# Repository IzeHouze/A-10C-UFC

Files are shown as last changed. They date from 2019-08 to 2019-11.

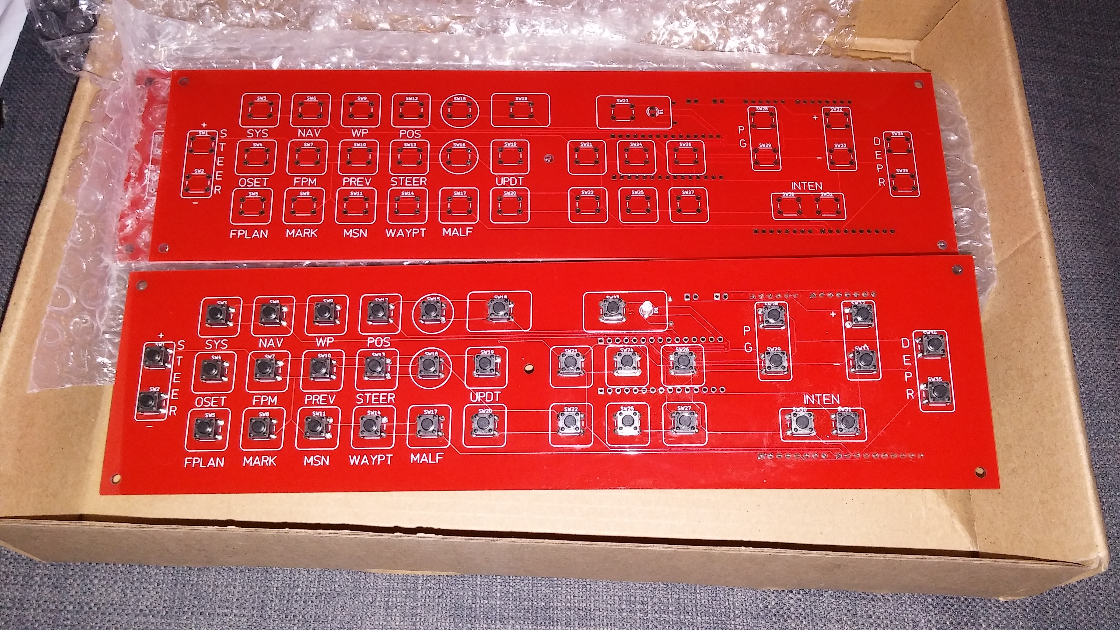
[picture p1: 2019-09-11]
CompletedFront.jpg

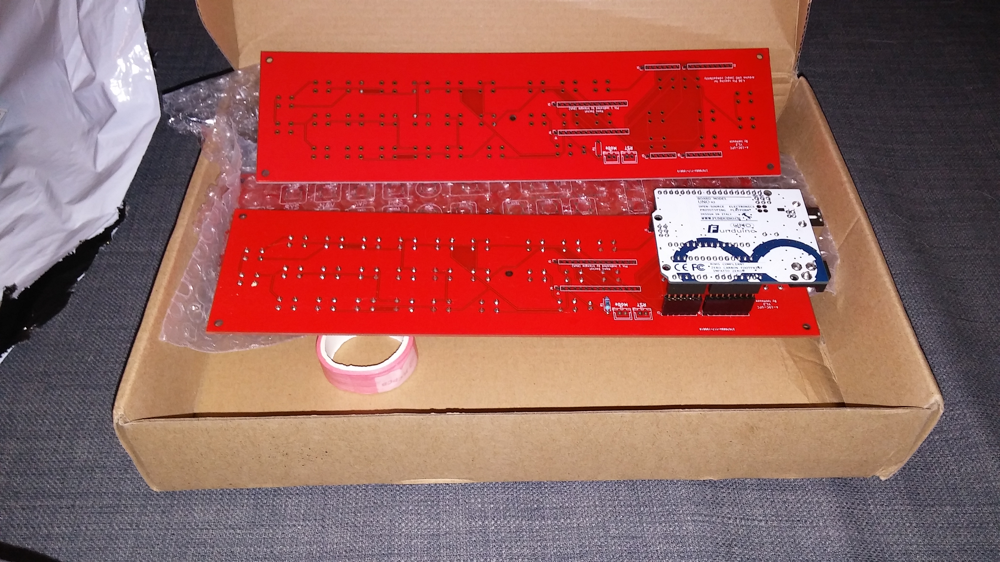
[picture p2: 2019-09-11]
CompletedBack.jpg

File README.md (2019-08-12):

# A-10C-UFC
DCS A-10C UFC

This project is basically a home grown attempt to create a functional UFC for the A-10C module of the flight sim DCS World.
It is based on a simple 6x6 keyboard matrix interfaced to the PC via an Arduino Microcontroller.  There are the wiring scematics, a PCB layout and Blender files for an enclosure which should be 3D printable.

The PCB has sockets for plug in capability of either the Uno or Nano variety of Arduino Controller.

The code was originally created to work specifically for the A-10C module, however, since the F/A-18 simulation also has a UFC, there is an optional connection for a switch which can be used to change modes between the A-10 and the F-18.  There is also a connector for an external reset switch, which would be best used once you change aircraft modes, reset the controller to have it reboot into the correct mode.

The required software would be:
  DCS-BIOS, preferably the branch that includes the F/A-18 support
  Arduino Studio
      Keypad Library for Arduino - Authors:  Mark Stanley, Alexander Brevig
      DCS-BIOS-Arduino Library 
        Original version - http://dcs-bios.a10c.de/
        Branch with F/A-18 support - https://forums.eagle.ru/showthread.php?t=210960
        
Optional software would be:
  KiCAD - for the schematics and PCB layout
  Blender - for the 3D printable components of an enclosure

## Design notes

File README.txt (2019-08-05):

A-10C
 This code is written for the custom PCB V1.2 created by Izehouze for the A-10C/F-18 
 As shown below this uses the 

 Keypad Library for Arduino
 Authors:  Mark Stanley, Alexander Brevig

 and DCS-BIOS from http://dcs-bios.a10c.de/

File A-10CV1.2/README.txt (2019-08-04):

This is designed in KiCAD 5.0.4

Front panel included using Front Panel Designer.

Both of these applications are free.

These are as-is and are not guaranteed.

In fact this is the 1.1 revision.
A noob mistake I found was that you cannot use Digital pins 0 and 1 if you use this card on a serial 
port, as those are Transmit and Receive for the USB COM port.

I have revised the schematics and layout to move those IOs to A0 and A1 on J3.

I have also added in the connections for a NANO.

And two JST connectors for an external reset button and a Mode selector switch for A-10 and F-18.

Happy BRRRRTing!

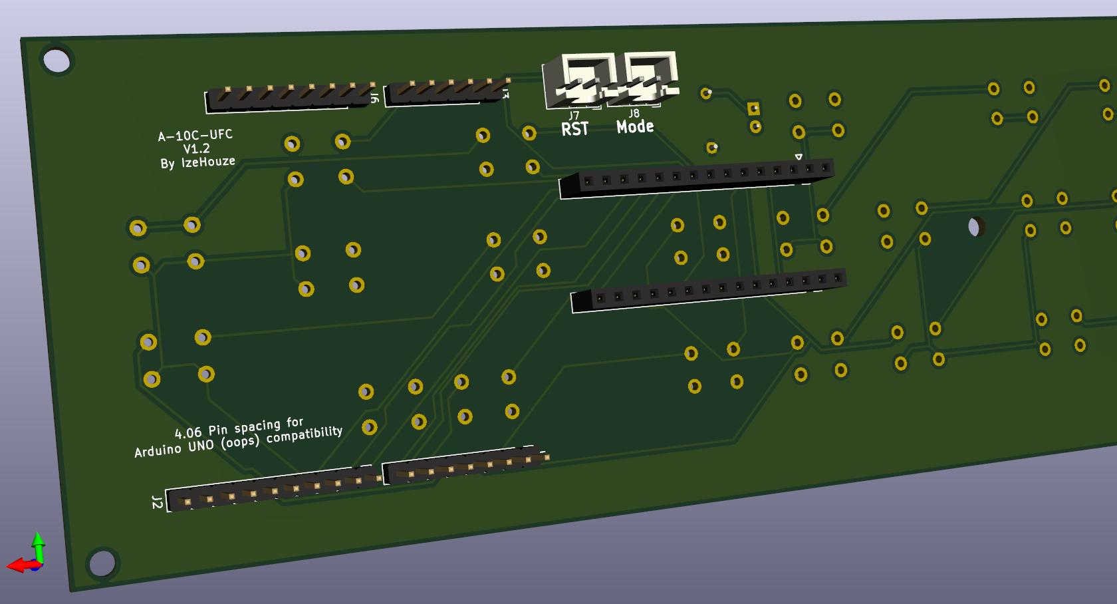
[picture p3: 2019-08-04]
A-10CV1.2/A-10C-UFC/A-10C-UFC-Back.jpg

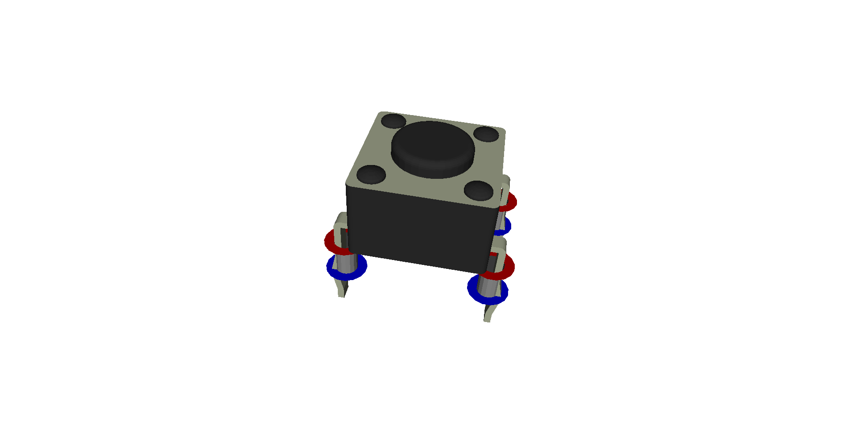
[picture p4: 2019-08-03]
A-10CV1.2/A-10C-UFC/models/Renderings/AB2_PB_MOM_6MM_PTH_BLK.png

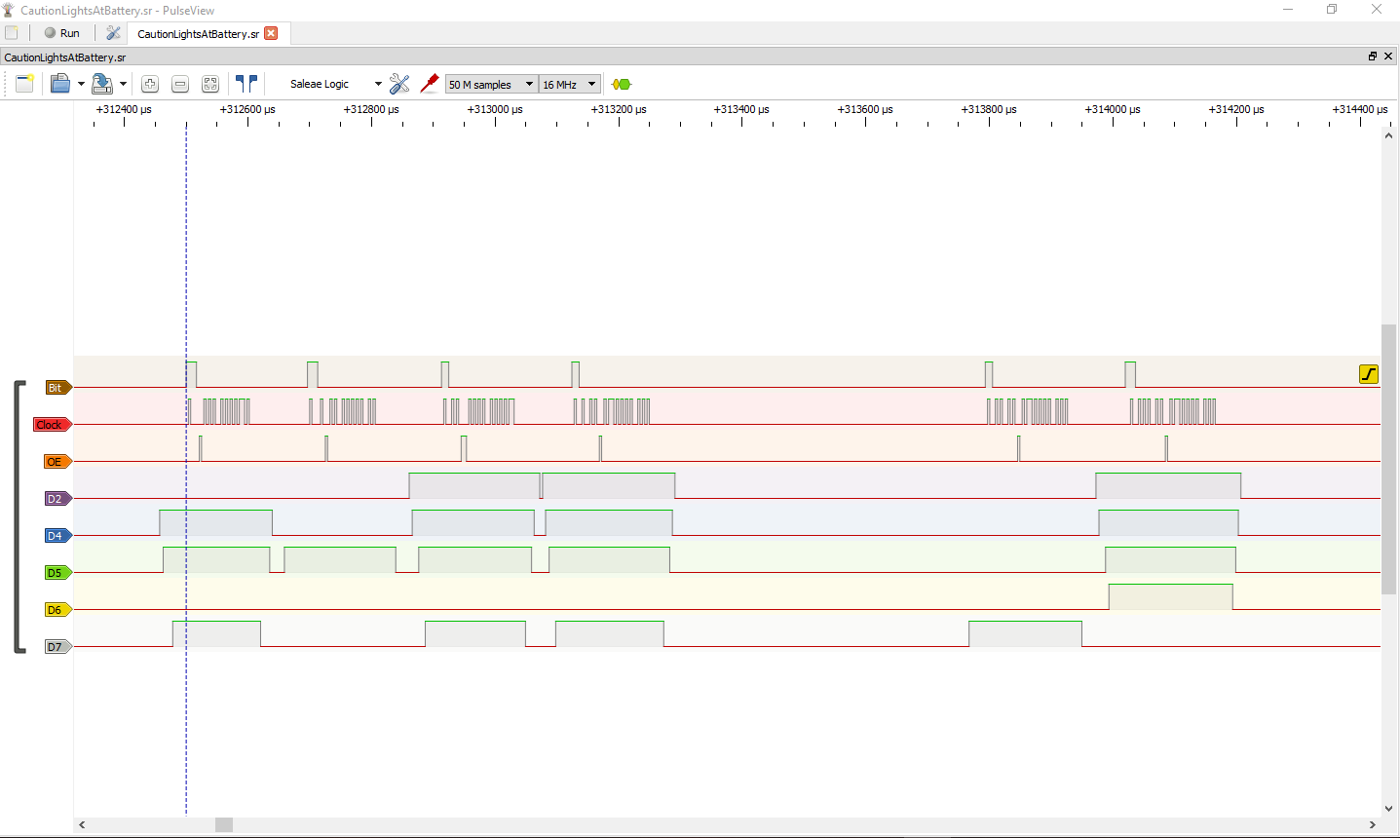
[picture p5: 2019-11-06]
A-10CV1.2/A-10C-CautionPanelNonMega/LogicAnalyzerA10CautionPanel.png

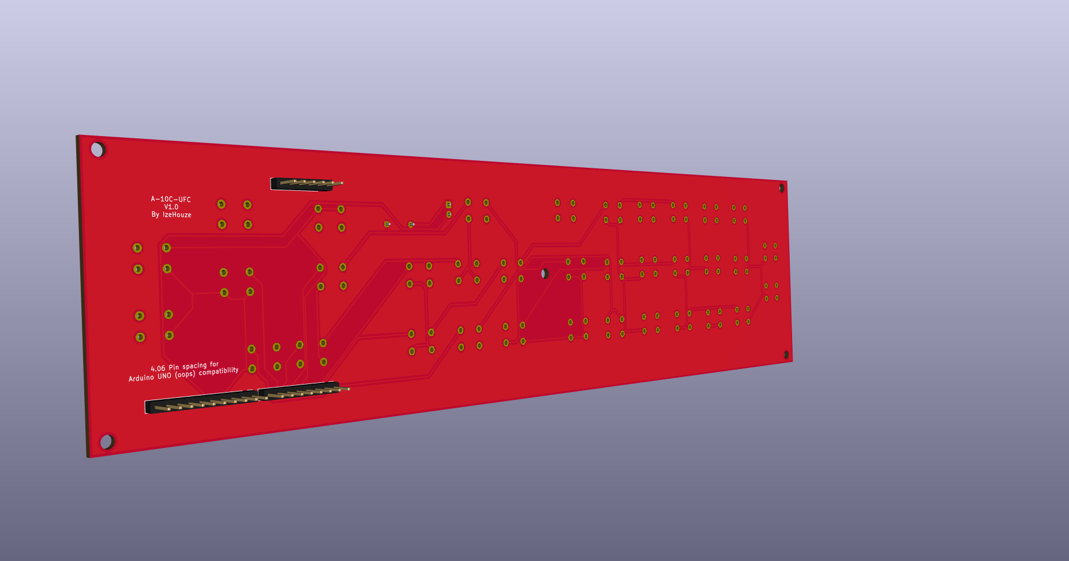
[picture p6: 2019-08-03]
A-10CV1.2/A-10C-UFC/A-10C-UFC.png

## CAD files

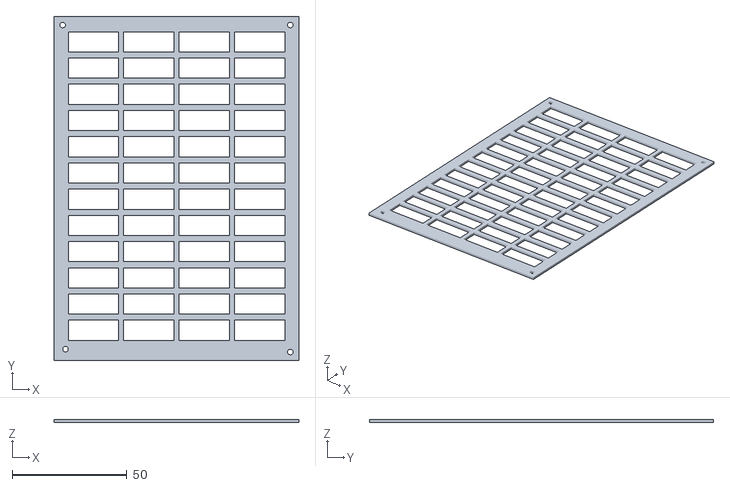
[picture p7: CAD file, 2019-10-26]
A-10CV1.2/A-10C-CautionLED/A10CautionLightBaseFace2.stl
106.6 x 149.8 x 1.27

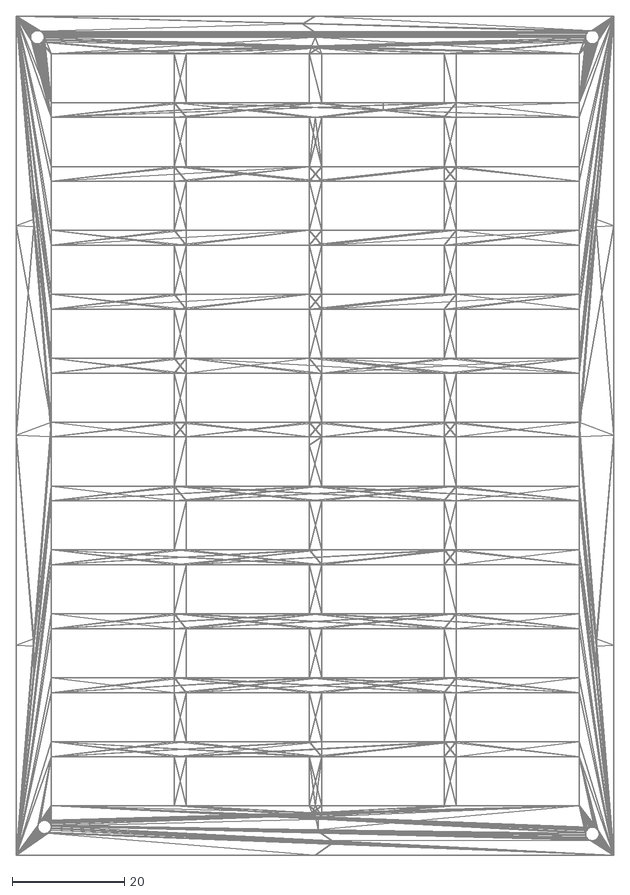
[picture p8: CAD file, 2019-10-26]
A-10CV1.2/A-10C-CautionLED/dxf/A10CautionLightBaseFace2.stl.dxf
106.6 x 149.8

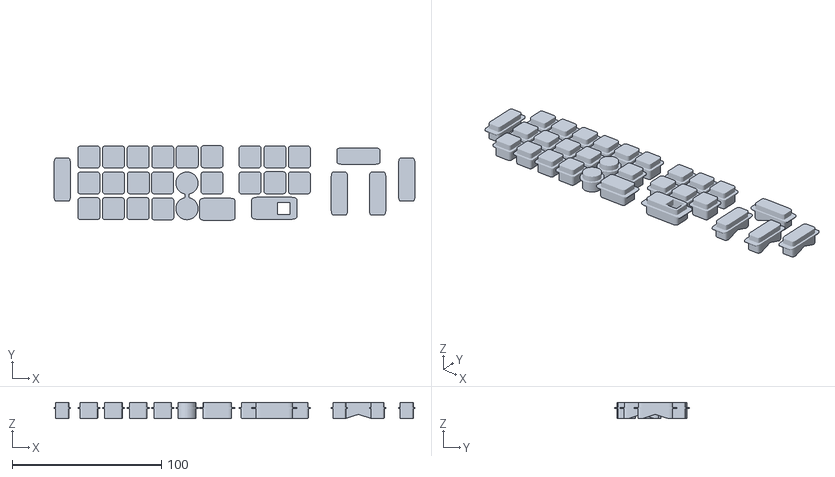
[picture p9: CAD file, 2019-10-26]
A-10CV1.2/A-10C-UFC/A10UFCButtons.stl
241.7 x 50.0 x 10.9

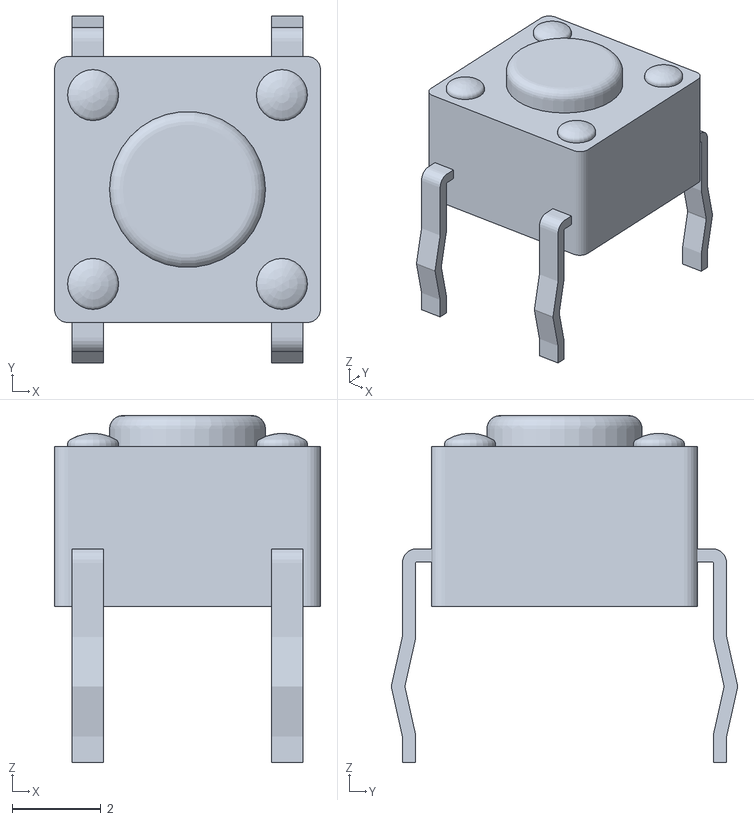
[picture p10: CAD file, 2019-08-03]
A-10CV1.2/A-10C-UFC/models/SW_PUSH_6mm.stl
5.99 x 7.80 x 7.81

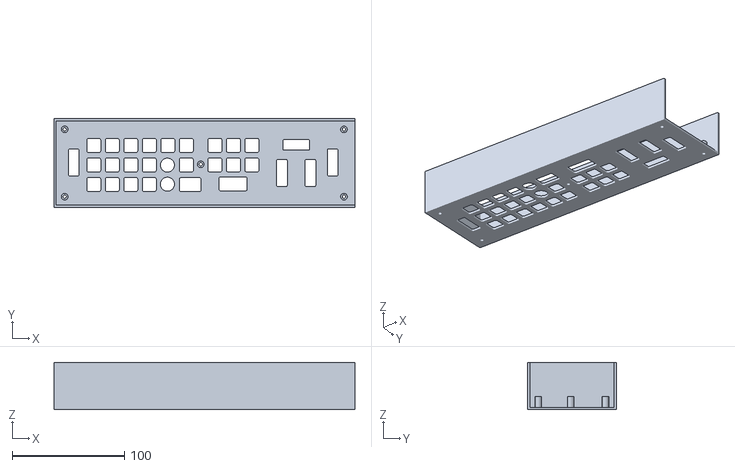
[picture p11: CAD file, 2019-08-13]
A-10CV1.2/A-10C-UFC/STLFiles/UFCCase.stl
268.4 x 79.0 x 42.0

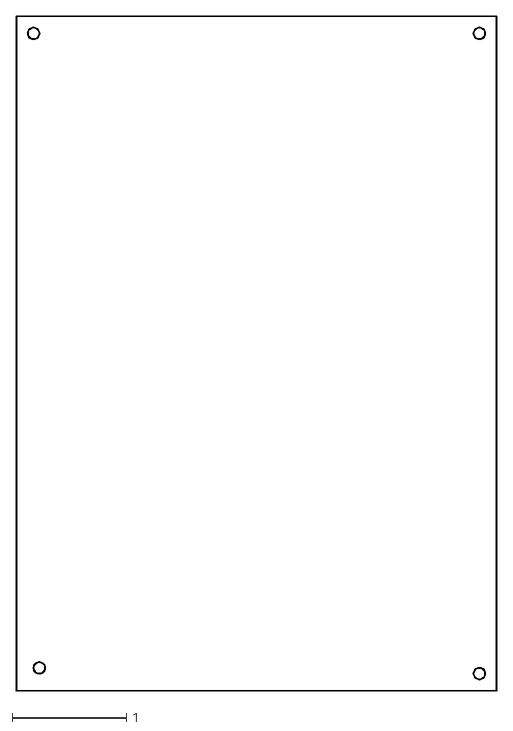
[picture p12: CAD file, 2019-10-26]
A-10CV1.2/A-10C-CautionLED/dxf/A-10C-CautionLED-Edge_Cuts.dxf
4.20 x 5.90

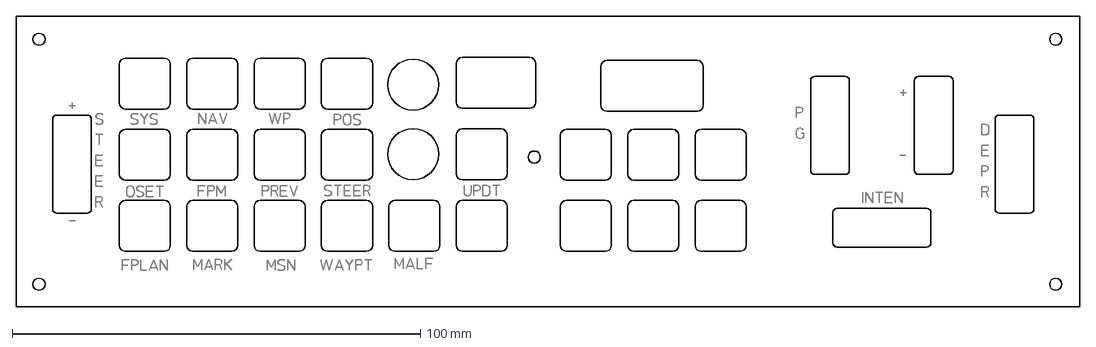
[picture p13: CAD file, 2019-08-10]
A-10CV1.2/A-10C-UFC/UFC.dxf
260.4 x 71.1 mm

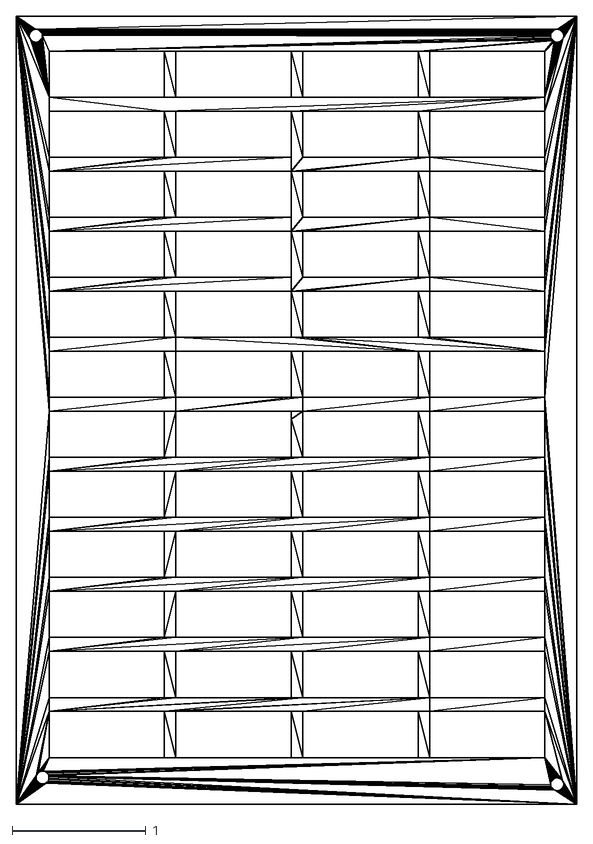
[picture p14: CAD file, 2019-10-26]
A-10CV1.2/A-10C-CautionLED/dxf/A10CautionLightBaseFace.blend.dxf
4.20 x 5.90

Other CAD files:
A-10CV1.2/A-10C-CautionLED/A10CautionLightBaseFace.stl
A-10CV1.2/A-10C-CautionLED/A10CautionLightBaseFace.blend
A-10CV1.2/A-10C-CautionLED/dxf/A-10C-CautionLED-F_SilkS.dxf
A-10CV1.2/A-10C-CautionLED/dxf/A10CautionLightBaseFace.dxf
A-10CV1.2/A-10C-UFC/A10UFC.blend
A-10CV1.2/A-10C-UFC/A10UFCRev.blend

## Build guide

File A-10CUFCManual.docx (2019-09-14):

# DCS UFC For the A-10C and F/A-18

# Contents:

- (36) 6x6mm tactile switches
- (1) 3mm LED (RED)
- (2) 15 pin header sockets (For the Arduino Nano)
- (1) 220 Ohm 1/4W Resistor
- (1) 4 pin header pin (split into 2 pin for Mode and Reset connections)

# Assembly:

For the most part, you should be able to use the silkscreens on the PCB to determine component locations and side of board.

Back side

- Headers
- Resistor

The 15 pin sockets are easiest to install using the Nano to hold them in place.

The (2) 2 pin headers are optional. One being for an external reset button, the other being for either a jumper or a single pole switch to change between A-10 or F-18 modes.

Front side

- LED – Short leg into square hole
- Buttons

# Software:

- Arduino Studio
- Keypad Library for Arduino from Mark Stanly, Alexander Brevig (install from Arduino Studio’s Library Manager)
- DCS-BIOS from http://dcs-bios.a10c.de/
  - If you want to use the F-18 mode, you must also upgrade to the version 1.0 branch from https://forums.eagle.ru/showthread.php?t=210960
- A-10C-UFC Sketch from https://github.com/IzeHouze/A-10C-UFC
  - Using Git, Clone from https://github.com/IzeHouze/A-10C-UFC.git

# Usage:

The PCB is designed to be run via an Arduino, Nano or Uno. The code will try to utilize the LEDs on board and the Master Caution of the PCB to also indicate if it is functioning and what mode it may be operating in.

Modes:

A-10C - The default mode if no jumpers are in place. J8 Open or not connected.

F/A-18 - Will change to this mode if you closed the Mode jumper, J8

To change modes, open or close the jumper with a hard jumper or using an external switch, then pressing the on-board or external reset button. Once reset, there will be two indicators to display which mode the board is now in.

Pin 13 LED On, Master Caution will blink twice = A-10

Pin 13 LED Off, Master Caution will blink four times = F-18

In A-10 mode, all buttons will match the position and function of the UFC in the simulator and “Real Life” with the only exception being the 6 buttons directly under the Master Caution Light and Reset. I have chosen to assign those 6 buttons to the power panel.

Battery On/Off

Inverter On/Off

APU Gen On/Off

Those buttons can be changed to any function supported by the DCS-BIOS API, by simply changing the code in the Arduino Sketch. Something to keep in mind would be the type of input you are assigning it to. Normally the buttons are assigned as On/Off, 1/0 as the button is pressed and released. As an example, when I changed it to work the power panel, it needs to emulate a two position switch where the top button is On, so the values need to be adjusted accordingly. The bottom buttons become the Off mode of a two position switch, so it needs to send a 0 when pressed, instead of a 1. Bearing in mind that if you emulate one of the rocker switches, it will act like a 3 position switch. 0 = Down, 1 = Neutral, 2 = Up.

In F/A-18 mode, I have only altered the bottom row of buttons to emulate the A/P IFF etc, starting at the button to the right on the “9” button (SW14). The number pad remains the same. If you wish you can assign other buttons to further act as F-18 UFC controls simply by adding the appropriate mode change code and AC Mode checks.

The panel connects to your PC via a USB port, which will be communicating to the game as a Serial Port device. The only thing you would need to do is to set up the connect-serial-port.cmd provided with DCS-BIOS to use the same port as configured as your Arduino Studio does when uploading sketches. The connect command can be started and stopped at any time when the DCS Game is running or not, but the board will not be able to talk to DCS unless the command is running.

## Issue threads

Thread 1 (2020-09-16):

Wiring plan + electrical components

Neodyn, 2020-09-16:
It is also possible to create a wiring plan and a list of the electrical components

IzeHouze, 2020-12-30:
Hi there!

Wiring diagrams are already in this Git.  Kikad diagrams.  Parts should be labeled correctly in diagram.
https://github.com/IzeHouze/A-10C-UFC/tree/master/A-10CV1.2/A-10C-UFC

Closed 2021-01-02.

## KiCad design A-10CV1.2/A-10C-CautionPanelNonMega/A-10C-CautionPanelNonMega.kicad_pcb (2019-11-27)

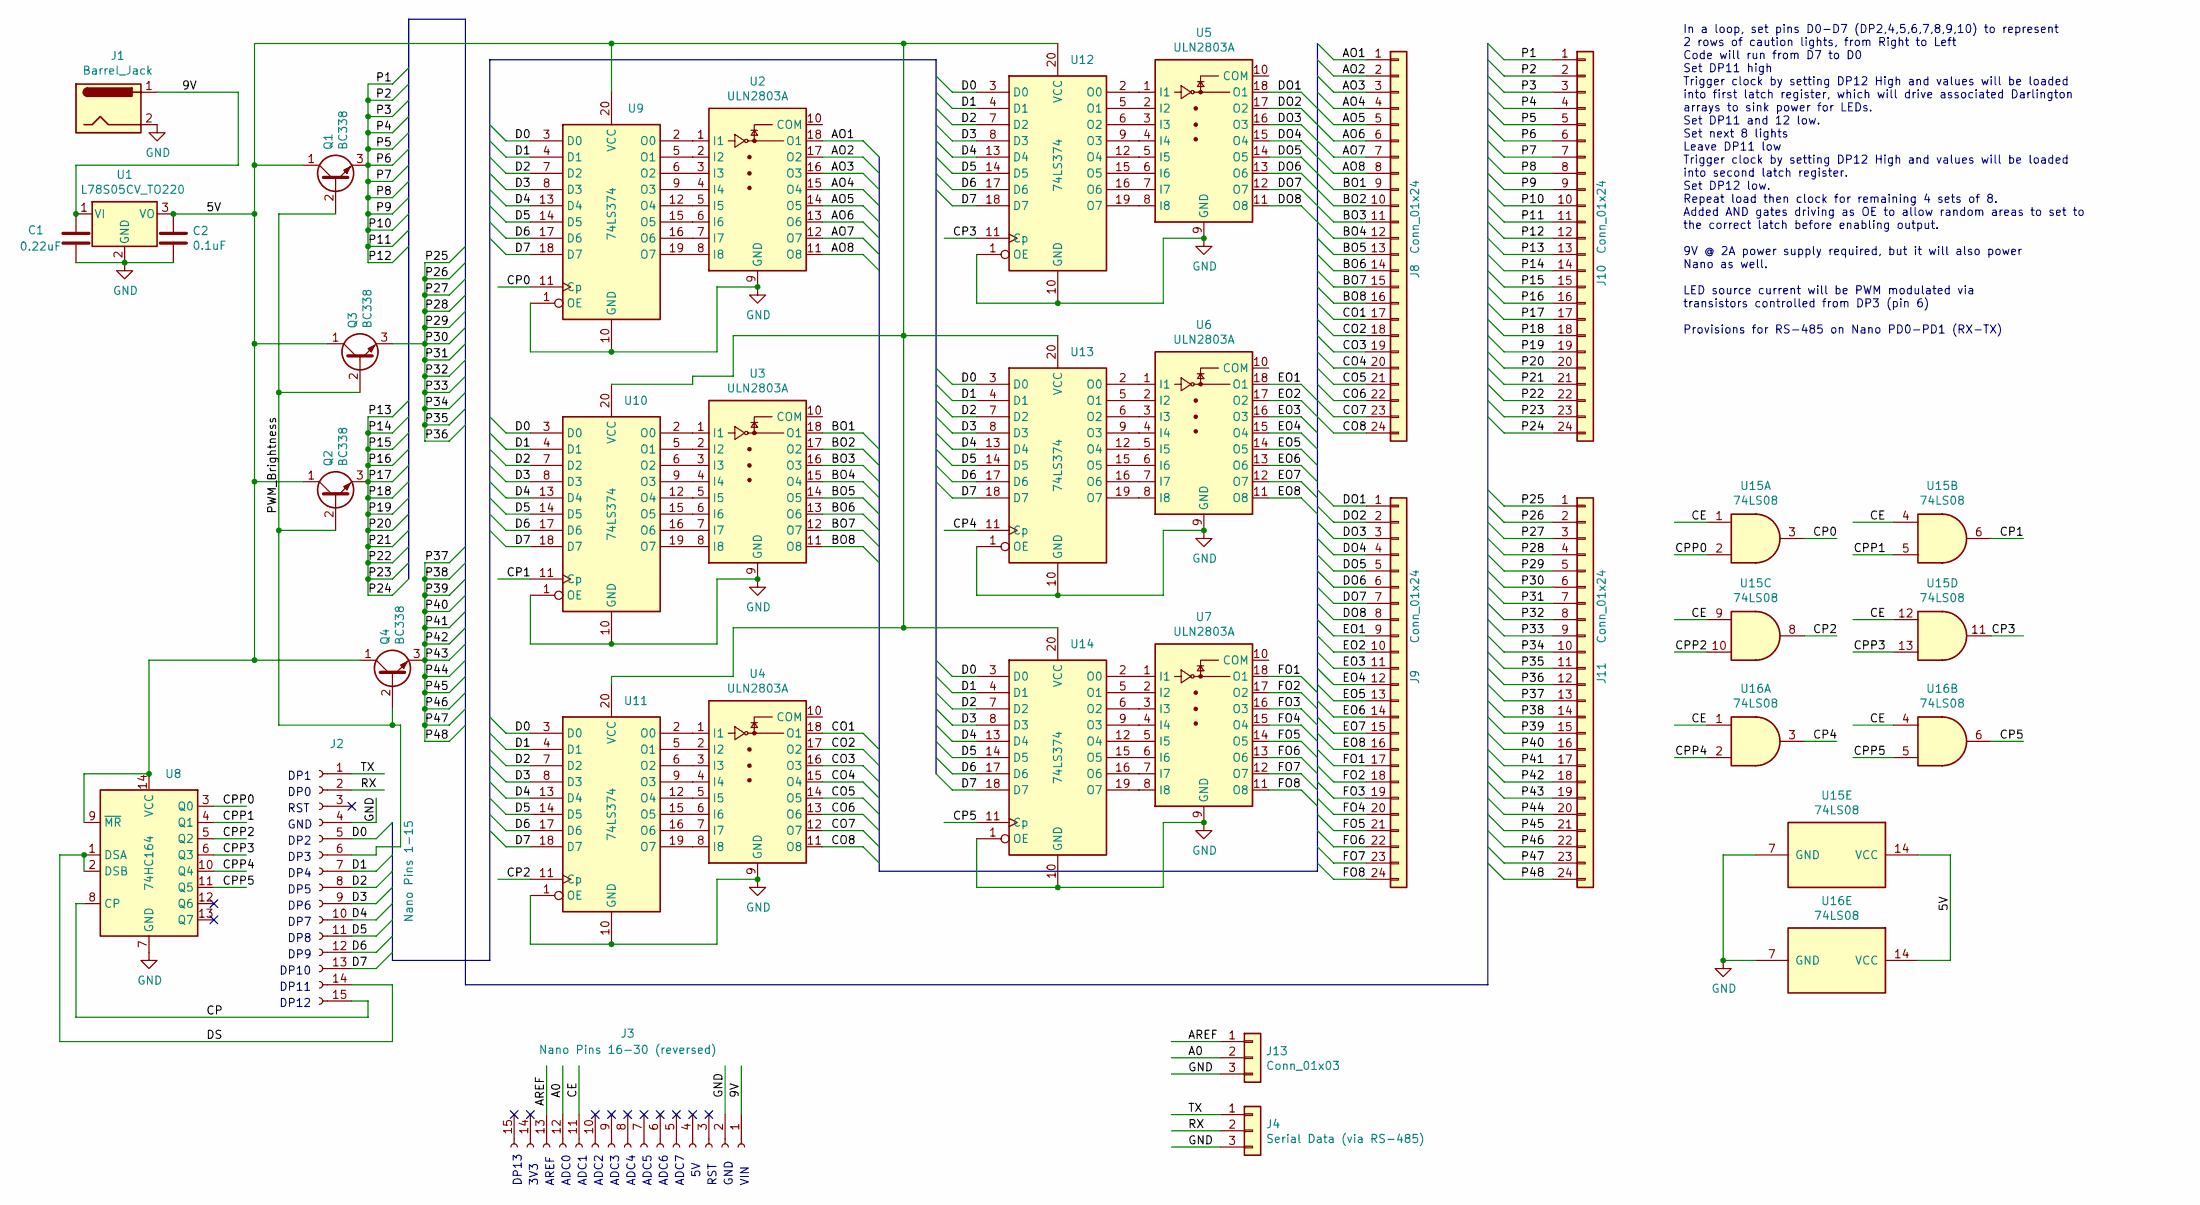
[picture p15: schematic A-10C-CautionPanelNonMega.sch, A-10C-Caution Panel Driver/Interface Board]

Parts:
C1: 0.22uF; C_Disc_D3.0mm_W2.0mm_P2.50mm
C2: 0.1uF; C_Disc_D3.0mm_W2.0mm_P2.50mm
J1: Barrel_Jack; BarrelJack_CUI_PJ-102AH_Horizontal
J2: Nano Pins 1-15; PinSocket_1x15_P2.54mm_Vertical
J3: Nano Pins 16-30 (reversed); PinSocket_1x15_P2.54mm_Vertical
J4: Serial Data (via RS-485); PinHeader_1x03_P2.54mm_Vertical
J8, J9, J10, J11: Conn_01x24; PinHeader_1x24_P2.54mm_Vertical
J13: Conn_01x03; PinHeader_1x03_P2.54mm_Vertical
Q1, Q2, Q3, Q4: BC338; TO-92_Inline
U1: L78S05CV_TO220; TO-220-3_Vertical
U2, U3, U4, U5, U6, U7: ULN2803A; DIP-18_W7.62mm
U8: 74HC164; DIP-14_W7.62mm
U9, U10, U11, U12, U13, U14: 74LS374; DIP-20_W7.62mm
U15, U16: 74LS08; DIP-14_W7.62mm

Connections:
/5V: C2.1, Q1.1 (C), Q2.1 (C), Q3.1 (C), Q4.1 (C), U1.3 (VO), U8.9 (~MR), U8.14 (VCC), U9.20 (VCC), U10.20 (VCC), U11.20 (VCC), U12.20 (VCC), U13.20 (VCC), U14.20 (VCC), U15.14 (VCC), U16.14 (VCC)
/9V: C1.1, J1.1, J3.1, U1.1 (VI)
/A0: J3.12, J13.2
/AO1: J8.1, U2.18 (O1)
/AO2: J8.2, U2.17 (O2)
/AO3: J8.3, U2.16 (O3)
/AO4: J8.4, U2.15 (O4)
/AO5: J8.5, U2.14 (O5)
/AO6: J8.6, U2.13 (O6)
/AO7: J8.7, U2.12 (O7)
/AO8: J8.8, U2.11 (O8)
/AREF: J3.13, J13.1
/BO1: J8.9, U3.18 (O1)
/BO2: J8.10, U3.17 (O2)
/BO3: J8.11, U3.16 (O3)
/BO4: J8.12, U3.15 (O4)
/BO5: J8.13, U3.14 (O5)
/BO6: J8.14, U3.13 (O6)
/BO7: J8.15, U3.12 (O7)
/BO8: J8.16, U3.11 (O8)
/CE: J3.11, U15.1, U15.4, U15.9, U15.12, U16.1, U16.4
/CO1: J8.17, U4.18 (O1)
/CO2: J8.18, U4.17 (O2)
/CO3: J8.19, U4.16 (O3)
/CO4: J8.20, U4.15 (O4)
/CO5: J8.21, U4.14 (O5)
/CO6: J8.22, U4.13 (O6)
/CO7: J8.23, U4.12 (O7)
/CO8: J8.24, U4.11 (O8)
/CP: J2.15, U8.8 (CP)
/CP0: U9.11 (Cp), U15.3
/CP1: U10.11 (Cp), U15.6
/CP2: U11.11 (Cp), U15.8
/CP3: U12.11 (Cp), U15.11
/CP4: U13.11 (Cp), U16.3
/CP5: U14.11 (Cp), U16.6
/CPP0: U8.3 (Q0), U15.2
/CPP1: U8.4 (Q1), U15.5
/CPP2: U8.5 (Q2), U15.10
/CPP3: U8.6 (Q3), U15.13
/CPP4: U8.10 (Q4), U16.2
/CPP5: U8.11 (Q5), U16.5
/D0: J2.5, U9.3 (D0), U10.3 (D0), U11.3 (D0), U12.3 (D0), U13.3 (D0), U14.3 (D0)
/D1: J2.7, U9.4 (D1), U10.4 (D1), U11.4 (D1), U12.4 (D1), U13.4 (D1), U14.4 (D1)
/D2: J2.8, U9.7 (D2), U10.7 (D2), U11.7 (D2), U12.7 (D2), U13.7 (D2), U14.7 (D2)
/D3: J2.9, U9.8 (D3), U10.8 (D3), U11.8 (D3), U12.8 (D3), U13.8 (D3), U14.8 (D3)
/D4: J2.10, U9.13 (D4), U10.13 (D4), U11.13 (D4), U12.13 (D4), U13.13 (D4), U14.13 (D4)
/D5: J2.11, U9.14 (D5), U10.14 (D5), U11.14 (D5), U12.14 (D5), U13.14 (D5), U14.14 (D5)
/D6: J2.12, U9.17 (D6), U10.17 (D6), U11.17 (D6), U12.17 (D6), U13.17 (D6), U14.17 (D6)
/D7: J2.13, U9.18 (D7), U10.18 (D7), U11.18 (D7), U12.18 (D7), U13.18 (D7), U14.18 (D7)
/DO1: J9.1, U5.18 (O1)
/DO2: J9.2, U5.17 (O2)
/DO3: J9.3, U5.16 (O3)
/DO4: J9.4, U5.15 (O4)
/DO5: J9.5, U5.14 (O5)
/DO6: J9.6, U5.13 (O6)
/DO7: J9.7, U5.12 (O7)
/DO8: J9.8, U5.11 (O8)
/DS: J2.14, U8.1 (DSA), U8.2 (DSB)
/EO1: J9.9, U6.18 (O1)
/EO2: J9.10, U6.17 (O2)
/EO3: J9.11, U6.16 (O3)
/EO4: J9.12, U6.15 (O4)
/EO5: J9.13, U6.14 (O5)
/EO6: J9.14, U6.13 (O6)
/EO7: J9.15, U6.12 (O7)
/EO8: J9.16, U6.11 (O8)
/FO1: J9.17, U7.18 (O1)
/FO2: J9.18, U7.17 (O2)
/FO3: J9.19, U7.16 (O3)
/FO4: J9.20, U7.15 (O4)
/FO5: J9.21, U7.14 (O5)
/FO6: J9.22, U7.13 (O6)
/FO7: J9.23, U7.12 (O7)
/FO8: J9.24, U7.11 (O8)
/P1: J10.1, J10.2, J10.3, J10.4, J10.5, J10.6, J10.7, J10.8, J10.9, J10.10, J10.11, J10.12, Q1.3 (E)
/P13: J10.13, J10.14, J10.15, J10.16, J10.17, J10.18, J10.19, J10.20, J10.21, J10.22, J10.23, J10.24, Q2.3 (E)
/P25: J11.1, J11.2, J11.3, J11.4, J11.5, J11.6, J11.7, J11.8, J11.9, J11.10, J11.11, J11.12, Q3.3 (E)
/P37: J11.13, J11.14, J11.15, J11.16, J11.17, J11.18, J11.19, J11.20, J11.21, J11.22, J11.23, J11.24, Q4.3 (E)
/PWM_Brightness: J2.6, Q1.2 (B), Q2.2 (B), Q3.2 (B), Q4.2 (B)
/RX: J2.2, J4.2
/TX: J2.1, J4.1
GND: C1.2, C2.2, J1.2, J2.4, J3.2, J4.3, J13.3, U1.2 (GND), U2.9 (GND), U3.9 (GND), U4.9 (GND), U5.9 (GND), U6.9 (GND), U7.9 (GND), U8.7 (GND), U9.1 (OE), U9.10 (GND), U10.1 (OE), U10.10 (GND), U11.1 (OE), U11.10 (GND), U12.1 (OE), U12.10 (GND), U13.1 (OE), U13.10 (GND), U14.1 (OE), U14.10 (GND), U15.7 (GND), U16.7 (GND)
unnamed: U2.1 (I1), U9.2 (O0)
unnamed: U2.2 (I2), U9.5 (O1)
unnamed: U2.3 (I3), U9.6 (O2)
unnamed: U2.4 (I4), U9.9 (O3)
unnamed: U2.5 (I5), U9.12 (O4)
unnamed: U2.6 (I6), U9.15 (O5)
unnamed: U2.7 (I7), U9.16 (O6)
unnamed: U2.8 (I8), U9.19 (O7)
unnamed: U3.1 (I1), U10.2 (O0)
unnamed: U3.2 (I2), U10.5 (O1)
unnamed: U3.3 (I3), U10.6 (O2)
unnamed: U3.4 (I4), U10.9 (O3)
unnamed: U3.5 (I5), U10.12 (O4)
unnamed: U3.6 (I6), U10.15 (O5)
unnamed: U3.7 (I7), U10.16 (O6)
unnamed: U3.8 (I8), U10.19 (O7)
unnamed: U4.1 (I1), U11.2 (O0)
unnamed: U4.2 (I2), U11.5 (O1)
unnamed: U4.3 (I3), U11.6 (O2)
unnamed: U4.4 (I4), U11.9 (O3)
unnamed: U4.5 (I5), U11.12 (O4)
unnamed: U4.6 (I6), U11.15 (O5)
unnamed: U4.7 (I7), U11.16 (O6)
unnamed: U4.8 (I8), U11.19 (O7)
unnamed: U5.1 (I1), U12.2 (O0)
unnamed: U5.2 (I2), U12.5 (O1)
unnamed: U5.3 (I3), U12.6 (O2)
unnamed: U5.4 (I4), U12.9 (O3)
unnamed: U5.5 (I5), U12.12 (O4)
unnamed: U5.6 (I6), U12.15 (O5)
unnamed: U5.7 (I7), U12.16 (O6)
unnamed: U5.8 (I8), U12.19 (O7)
unnamed: U6.1 (I1), U13.2 (O0)
unnamed: U6.2 (I2), U13.5 (O1)
unnamed: U6.3 (I3), U13.6 (O2)
unnamed: U6.4 (I4), U13.9 (O3)
unnamed: U6.5 (I5), U13.12 (O4)
unnamed: U6.6 (I6), U13.15 (O5)
unnamed: U6.7 (I7), U13.16 (O6)
unnamed: U6.8 (I8), U13.19 (O7)
unnamed: U7.1 (I1), U14.2 (O0)
unnamed: U7.2 (I2), U14.5 (O1)
unnamed: U7.3 (I3), U14.6 (O2)
unnamed: U7.4 (I4), U14.9 (O3)
unnamed: U7.5 (I5), U14.12 (O4)
unnamed: U7.6 (I6), U14.15 (O5)
unnamed: U7.7 (I7), U14.16 (O6)
unnamed: U7.8 (I8), U14.19 (O7)

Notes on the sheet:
In a loop, set pins D0-D7 (DP2,4,5,6,7,8,9,10) to represent 2 rows of caution lights, from Right to Left Code will run from D7 to D0 Set DP11 high Trigger clock by setting DP12 High and values will be loaded into first latch register, which will drive associated Darlington arrays to sink power for 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
DP3
DP4
DP5
DP6
DP7
DP8
DP9
DP10
GND
DP2
RST
DP0
DP1
DP11
DP12
DP13
3V3
AREF
ADC0
ADC1
ADC2
ADC3
ADC4
ADC5
ADC6
ADC7
VIN

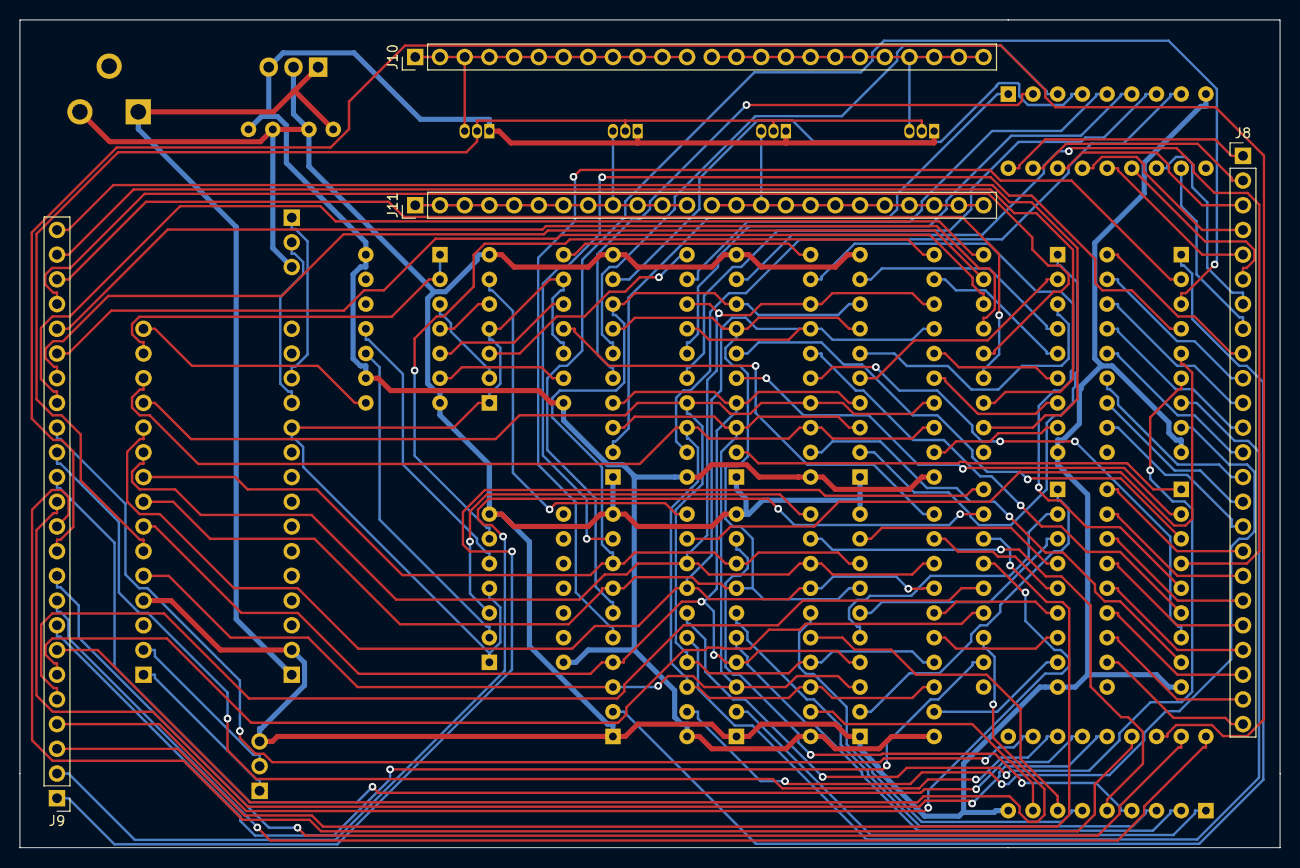
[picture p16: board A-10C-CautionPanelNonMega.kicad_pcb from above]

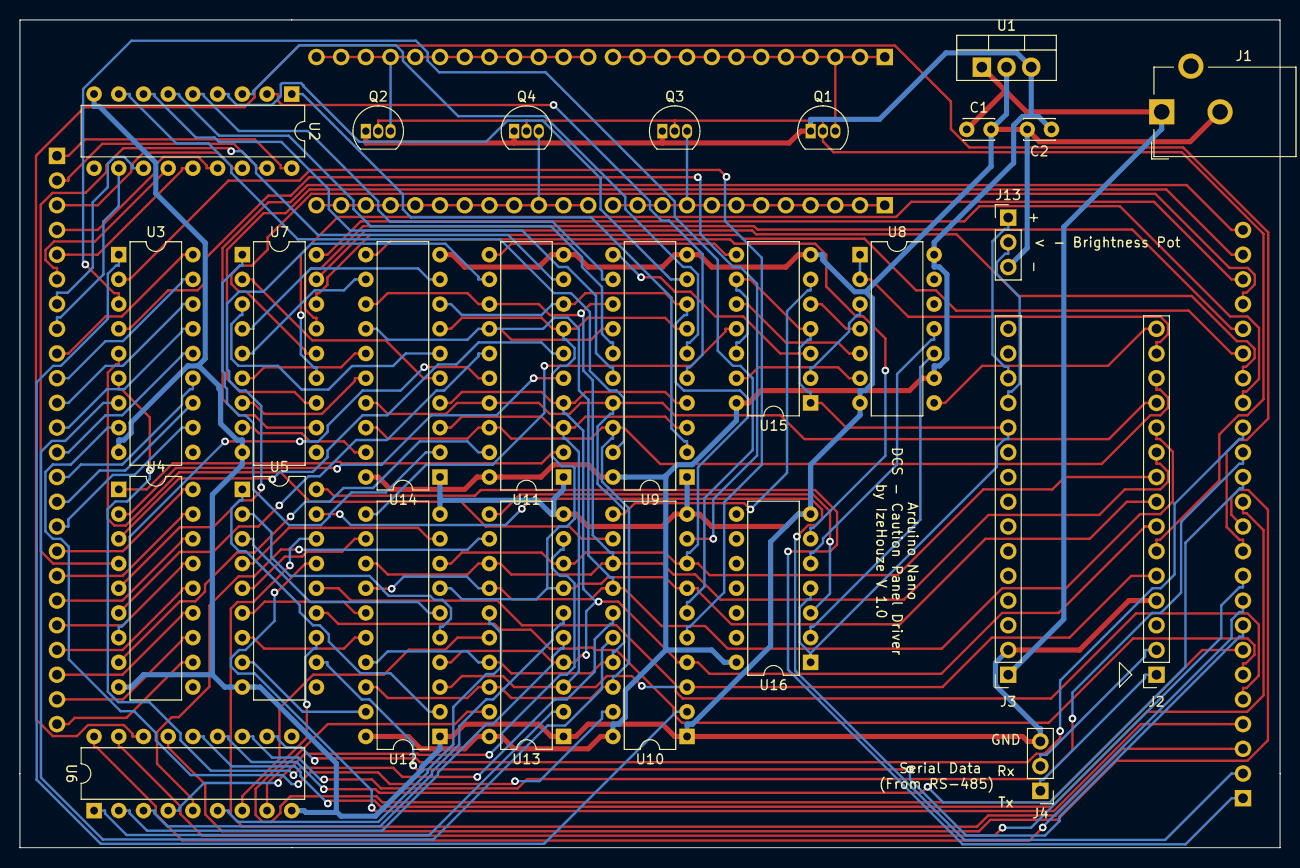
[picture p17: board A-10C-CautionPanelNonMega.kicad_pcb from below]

Board: 2 copper layers, 129.5 x 85.1 mm, 31 parts (27 on the bottom side), 131 nets.

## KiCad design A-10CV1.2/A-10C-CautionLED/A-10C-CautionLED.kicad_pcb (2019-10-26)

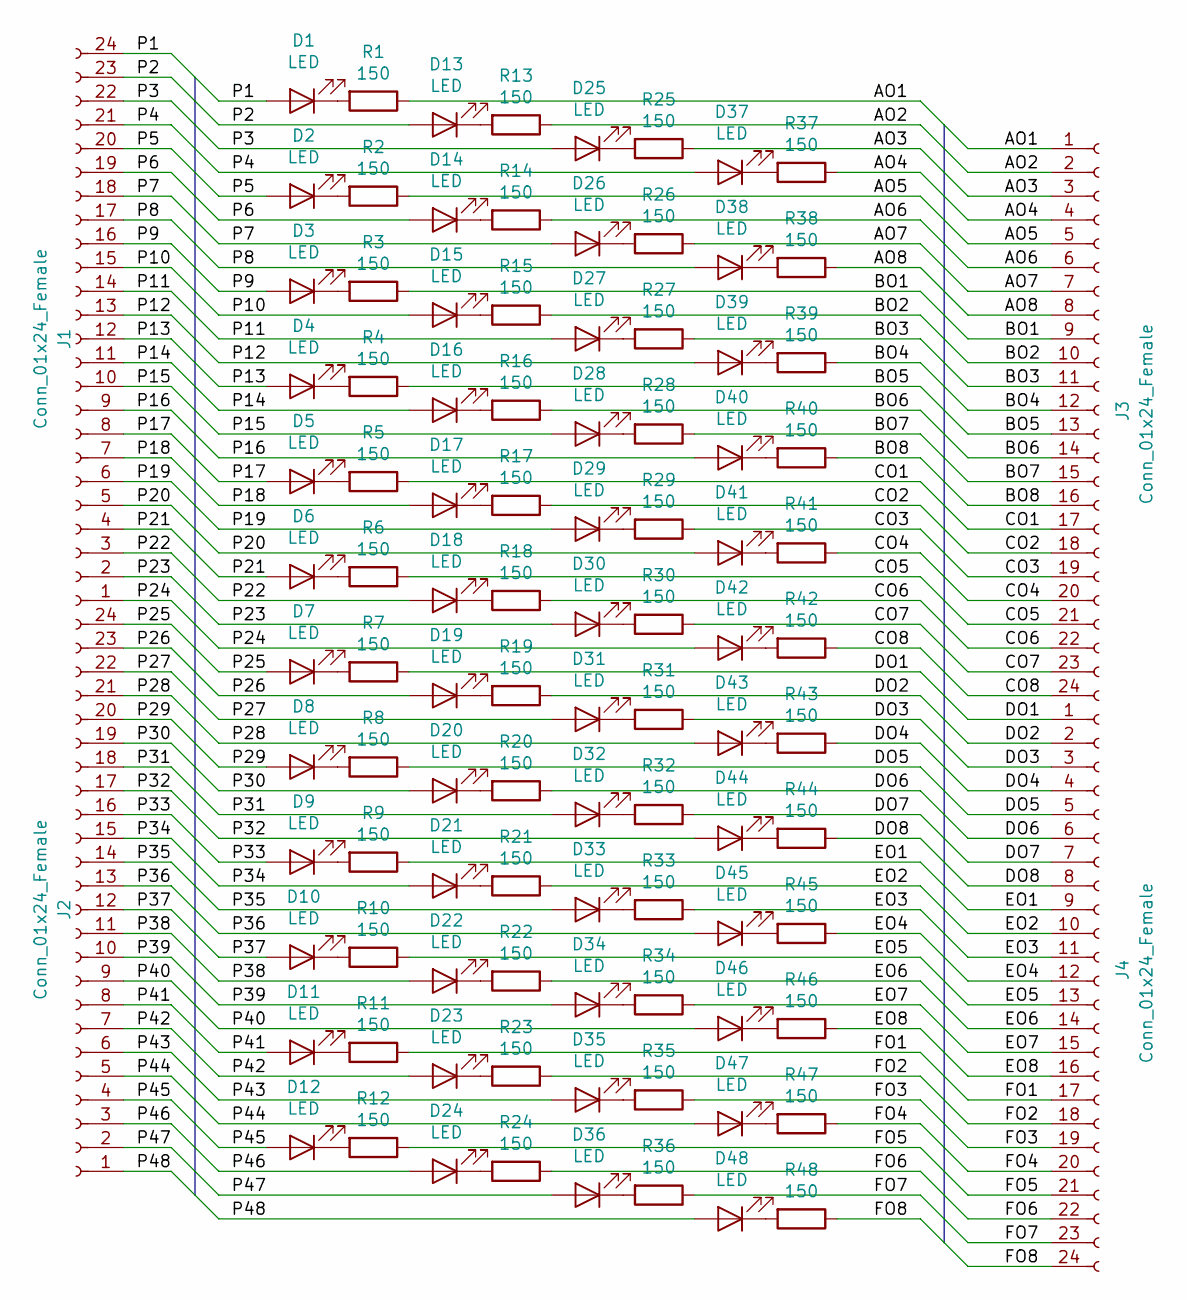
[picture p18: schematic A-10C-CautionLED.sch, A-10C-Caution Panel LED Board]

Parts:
D1, D2, D3, D4, D5, D6, D7, D8, D9, D10, D11, D12, D13, D14, D15, D16, D17, D18, D19, D20, D21, D22, D23, D24, D25, D26, D27, D28, D29, D30, D31, D32, D33, D34, D35, D36, D37, D38, D39, D40, D41, D42, D43, D44, D45, D46, D47, D48: LED; LED_D3.0mm
J1, J2, J3, J4: Conn_01x24_Female; PinSocket_1x24_P2.54mm_Vertical
R1, R2, R3, R4, R5, R6, R7, R8, R9, R10, R11, R12, R13, R14, R15, R16, R17, R18, R19, R20, R21, R22, R23, R24, R25, R26, R27, R28, R29, R30, R31, R32, R33, R34, R35, R36, R37, R38, R39, R40, R41, R42, R43, R44, R45, R46, R47, R48: 150; R_Axial_DIN0207_L6.3mm_D2.5mm_P7.62mm_Horizontal

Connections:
/AO1: J3.1, R1.1
/AO2: J3.2, R13.1
/AO3: J3.3, R25.1
/AO4: J3.4, R37.1
/AO5: J3.5, R2.1
/AO6: J3.6, R14.1
/AO7: J3.7, R26.1
/AO8: J3.8, R38.1
/BO1: J3.9, R3.1
/BO2: J3.10, R15.1
/BO3: J3.11, R27.1
/BO4: J3.12, R39.1
/BO5: J3.13, R4.1
/BO6: J3.14, R16.1
/BO7: J3.15, R28.1
/BO8: J3.16, R40.1
/CO1: J3.17, R5.1
/CO2: J3.18, R17.1
/CO3: J3.19, R29.1
/CO4: J3.20, R41.1
/CO5: J3.21, R6.1
/CO6: J3.22, R18.1
/CO7: J3.23, R30.1
/CO8: J3.24, R42.1
/DO1: J4.1, R7.1
/DO2: J4.2, R19.1
/DO3: J4.3, R31.1
/DO4: J4.4, R43.1
/DO5: J4.5, R8.1
/DO6: J4.6, R20.1
/DO7: J4.7, R32.1
/DO8: J4.8, R44.1
/EO1: J4.9, R9.1
/EO2: J4.10, R21.1
/EO3: J4.11, R33.1
/EO4: J4.12, R45.1
/EO5: J4.13, R10.1
/EO6: J4.14, R22.1
/EO7: J4.15, R34.1
/EO8: J4.16, R46.1
/FO1: J4.17, R11.1
/FO2: J4.18, R23.1
/FO3: J4.19, R35.1
/FO4: J4.20, R47.1
/FO5: J4.21, R12.1
/FO6: J4.22, R24.1
/FO7: J4.23, R36.1
/FO8: J4.24, R48.1
/P1: D1.2 (A), J1.24
/P2: D13.2 (A), J1.23
/P3: D25.2 (A), J1.22
/P4: D37.2 (A), J1.21
/P5: D2.2 (A), J1.20
/P6: D14.2 (A), J1.19
/P7: D26.2 (A), J1.18
/P8: D38.2 (A), J1.17
/P9: D3.2 (A), J1.16
/P10: D15.2 (A), J1.15
/P11: D27.2 (A), J1.14
/P12: D39.2 (A), J1.13
/P13: D4.2 (A), J1.12
/P14: D16.2 (A), J1.11
/P15: D28.2 (A), J1.10
/P16: D40.2 (A), J1.9
/P17: D5.2 (A), J1.8
/P18: D17.2 (A), J1.7
/P19: D29.2 (A), J1.6
/P20: D41.2 (A), J1.5
/P21: D6.2 (A), J1.4
/P22: D18.2 (A), J1.3
/P23: D30.2 (A), J1.2
/P24: D42.2 (A), J1.1
/P25: D7.2 (A), J2.24
/P26: D19.2 (A), J2.23
/P27: D31.2 (A), J2.22
/P28: D43.2 (A), J2.21
/P29: D8.2 (A), J2.20
/P30: D20.2 (A), J2.19
/P31: D32.2 (A), J2.18
/P32: D44.2 (A), J2.17
/P33: D9.2 (A), J2.16
/P34: D21.2 (A), J2.15
/P35: D33.2 (A), J2.14
/P36: D45.2 (A), J2.13
/P37: D10.2 (A), J2.12
/P38: D22.2 (A), J2.11
/P39: D34.2 (A), J2.10
/P40: D46.2 (A), J2.9
/P41: D11.2 (A), J2.8
/P42: D23.2 (A), J2.7
/P43: D35.2 (A), J2.6
/P44: D47.2 (A), J2.5
/P45: D12.2 (A), J2.4
/P46: D24.2 (A), J2.3
/P47: D36.2 (A), J2.2
/P48: D48.2 (A), J2.1
unnamed: D1.1 (K), R1.2
unnamed: D2.1 (K), R2.2
unnamed: D3.1 (K), R3.2
unnamed: D4.1 (K), R4.2
unnamed: D5.1 (K), R5.2
unnamed: D6.1 (K), R6.2
unnamed: D7.1 (K), R7.2
unnamed: D8.1 (K), R8.2
unnamed: D9.1 (K), R9.2
unnamed: D10.1 (K), R10.2
unnamed: D11.1 (K), R11.2
unnamed: D12.1 (K), R12.2
unnamed: D13.1 (K), R13.2
unnamed: D14.1 (K), R14.2
unnamed: D15.1 (K), R15.2
unnamed: D16.1 (K), R16.2
unnamed: D17.1 (K), R17.2
unnamed: D18.1 (K), R18.2
unnamed: D19.1 (K), R19.2
unnamed: D20.1 (K), R20.2
unnamed: D21.1 (K), R21.2
unnamed: D22.1 (K), R22.2
unnamed: D23.1 (K), R23.2
unnamed: D24.1 (K), R24.2
unnamed: D25.1 (K), R25.2
unnamed: D26.1 (K), R26.2
unnamed: D27.1 (K), R27.2
unnamed: D28.1 (K), R28.2
unnamed: D29.1 (K), R29.2
unnamed: D30.1 (K), R30.2
unnamed: D31.1 (K), R31.2
unnamed: D32.1 (K), R32.2
unnamed: D33.1 (K), R33.2
unnamed: D34.1 (K), R34.2
unnamed: D35.1 (K), R35.2
unnamed: D36.1 (K), R36.2
unnamed: D37.1 (K), R37.2
unnamed: D38.1 (K), R38.2
unnamed: D39.1 (K), R39.2
unnamed: D40.1 (K), R40.2
unnamed: D41.1 (K), R41.2
unnamed: D42.1 (K), R42.2
unnamed: D43.1 (K), R43.2
unnamed: D44.1 (K), R44.2
unnamed: D45.1 (K), R45.2
unnamed: D46.1 (K), R46.2
unnamed: D47.1 (K), R47.2
unnamed: D48.1 (K), R48.2

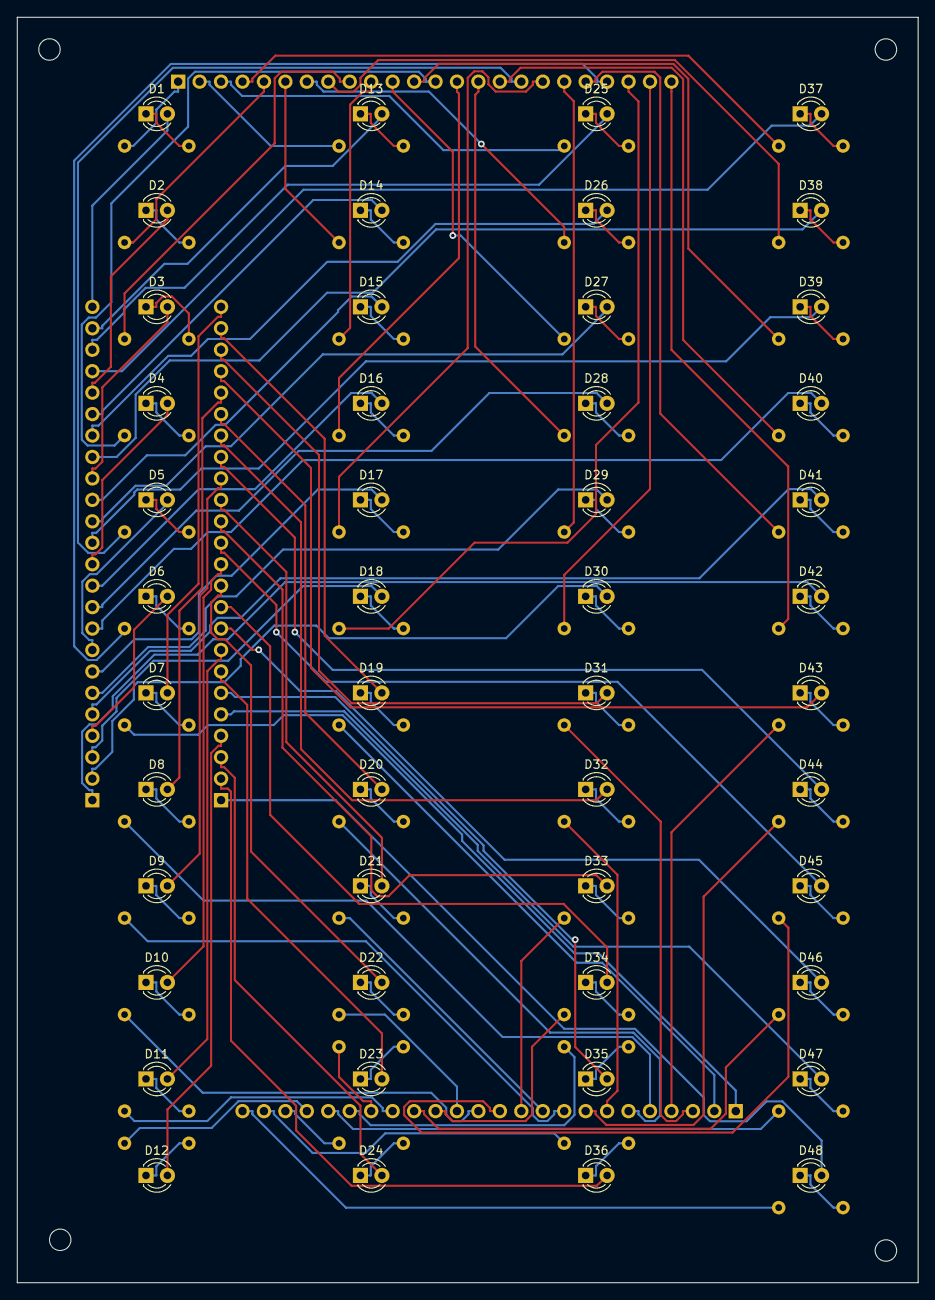
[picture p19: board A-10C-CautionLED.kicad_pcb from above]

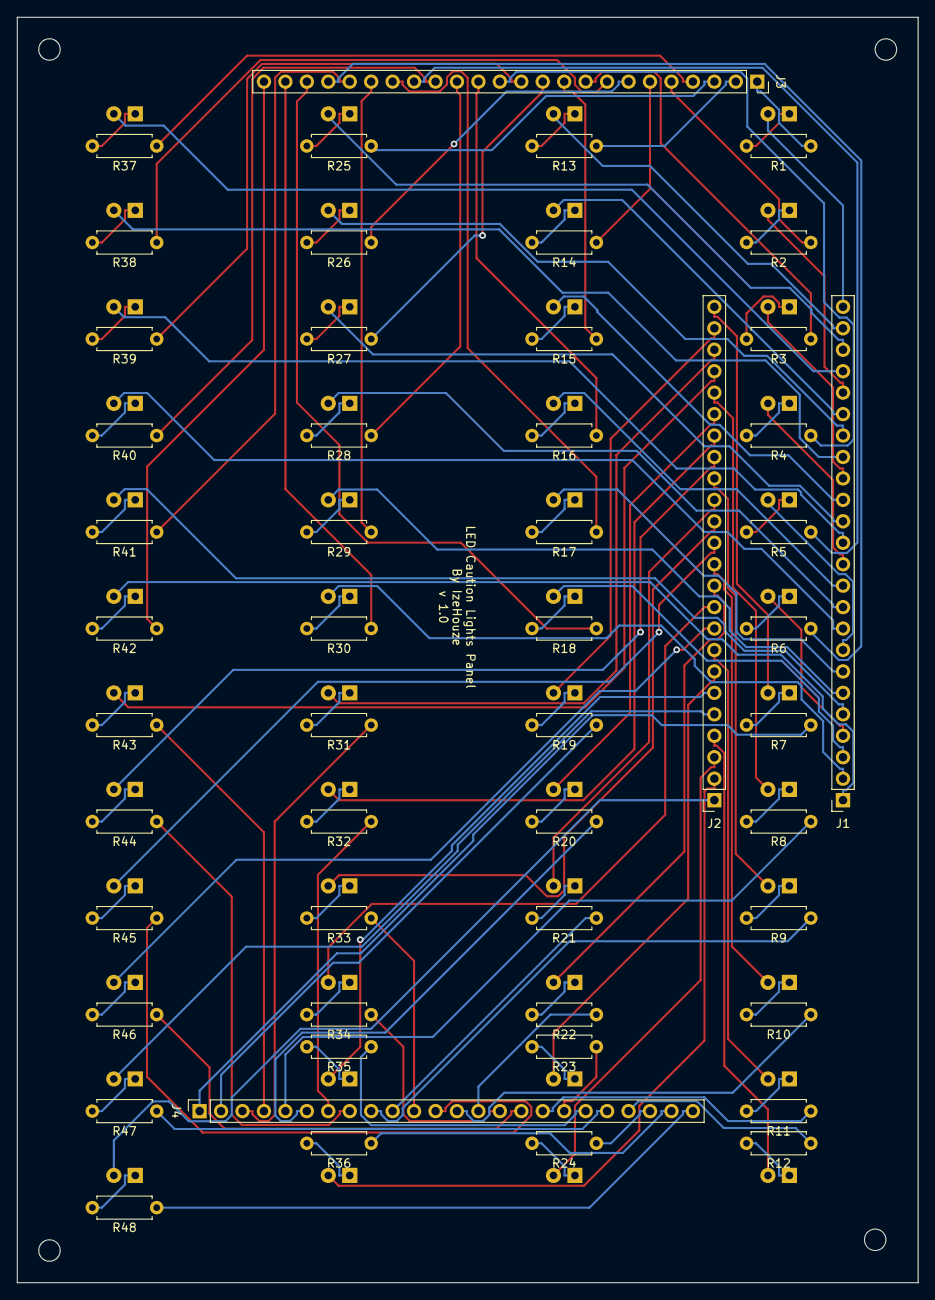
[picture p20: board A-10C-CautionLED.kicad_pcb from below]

Board: 2 copper layers, 106.7 x 149.9 mm, 100 parts (52 on the bottom side), 144 nets.

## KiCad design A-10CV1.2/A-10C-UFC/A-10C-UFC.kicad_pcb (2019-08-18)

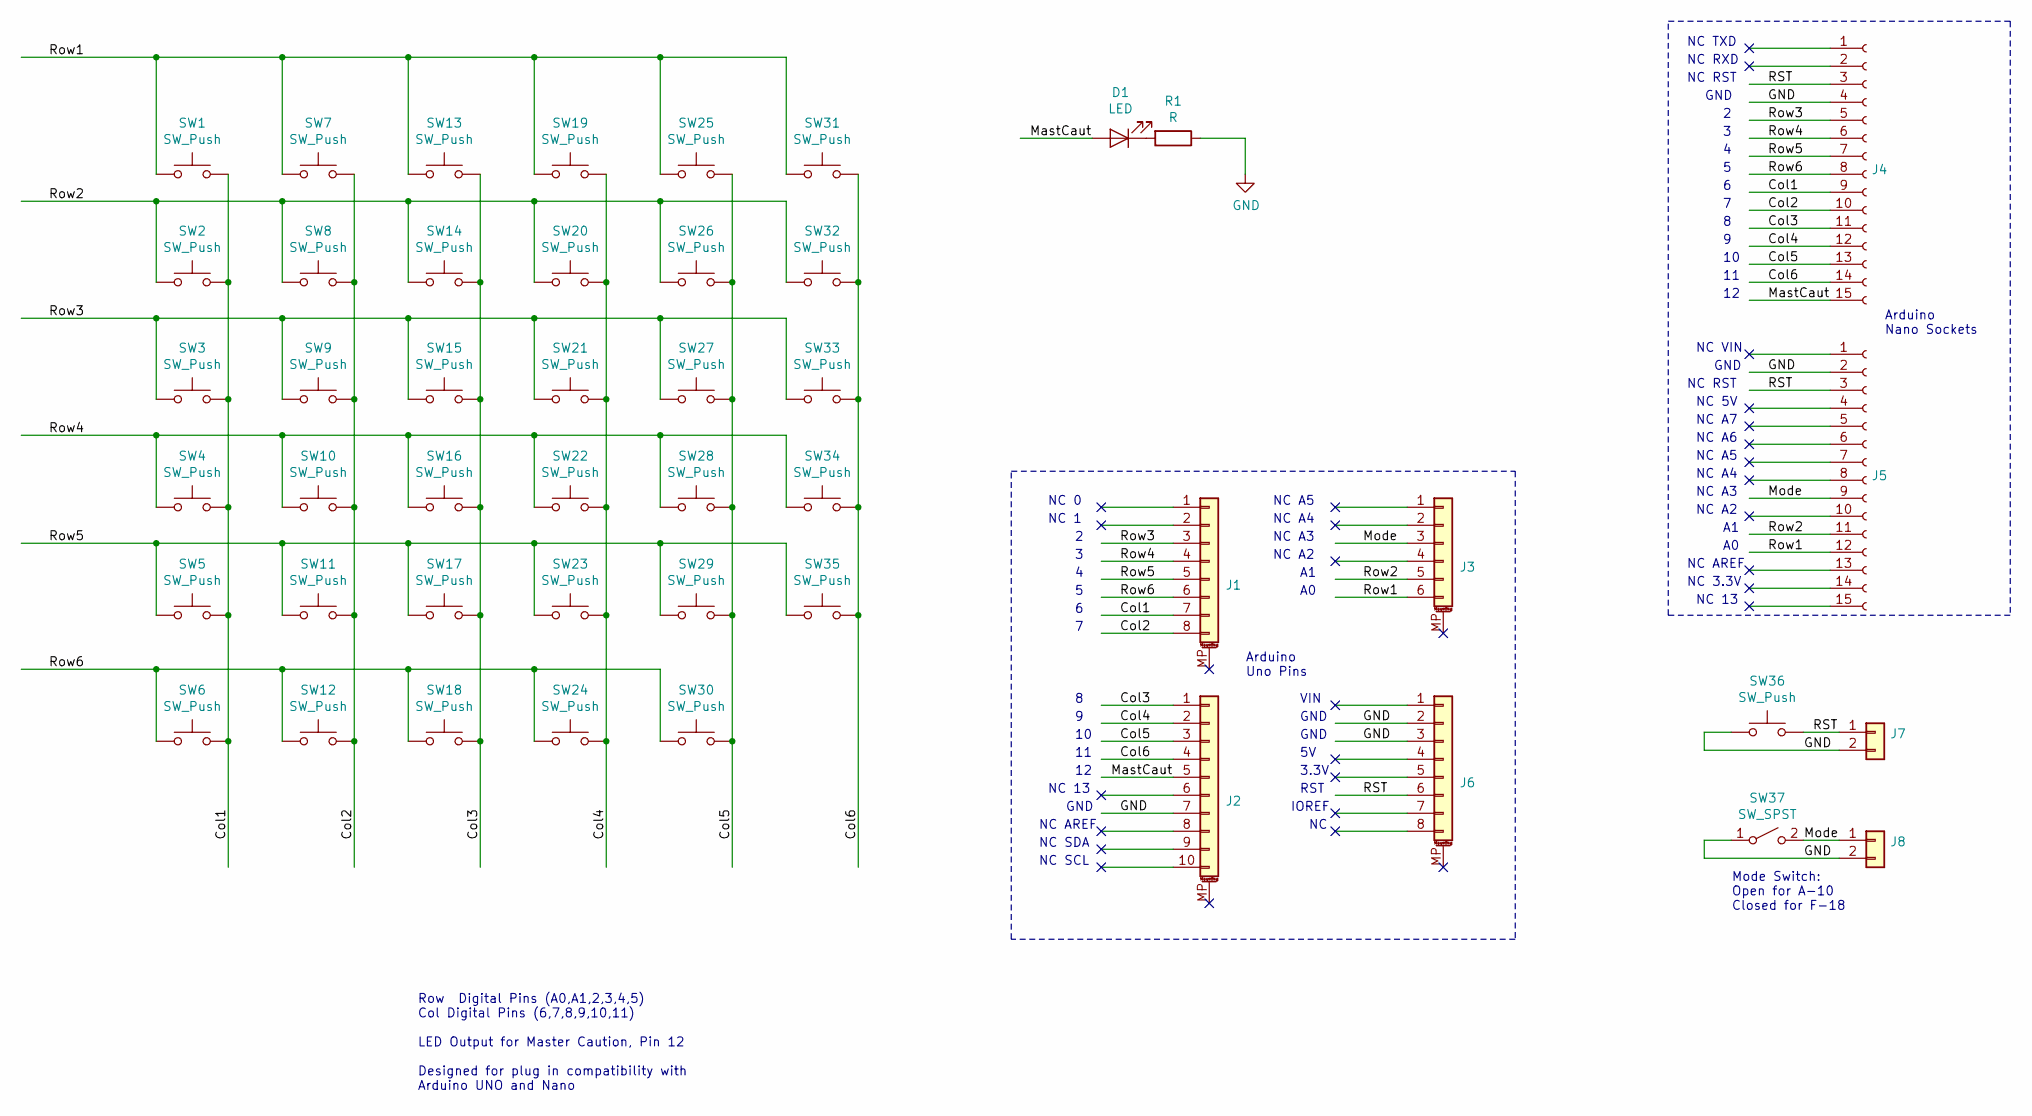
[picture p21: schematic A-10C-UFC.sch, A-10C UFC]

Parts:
D1: LED; LED_D3.0mm
J1, J6: Conn_01x08_MountingPin; PinHeader_1x08_P2.54mm_Vertical
J2: Conn_01x10_MountingPin; PinHeader_1x10_P2.54mm_Vertical
J3: Conn_01x06_MountingPin; PinHeader_1x06_P2.54mm_Vertical
J4, J5: Conn_01x15_Female; PinSocket_1x15_P2.54mm_Vertical
J7, J8: Conn_01x02; JST_XH_B02B-XH-A_1x02_P2.50mm_Vertical
R1: R; R_Axial_DIN0207_L6.3mm_D2.5mm_P7.62mm_Horizontal
SW1, SW2, SW3, SW4, SW5, SW6, SW7, SW8, SW9, SW10, SW11, SW12, SW13, SW14, SW15, SW16, SW17, SW18, SW19, SW20, SW21, SW22, SW23, SW24, SW25, SW26, SW27, SW28, SW29, SW30, SW31, SW32, SW33, SW34, SW35: SW_Push; SW_PUSH_6mm
SW36: SW_Push
SW37: SW_SPST

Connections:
/Col1: J1.7, J4.9, SW1.2, SW2.2, SW3.2, SW4.2, SW5.2, SW6.2
/Col2: J1.8, J4.10, SW7.2, SW8.2, SW9.2, SW10.2, SW11.2, SW12.2
/Col3: J2.1, J4.11, SW13.2, SW14.2, SW15.2, SW16.2, SW17.2, SW18.2
/Col4: J2.2, J4.12, SW19.2, SW20.2, SW21.2, SW22.2, SW23.2, SW24.2
/Col5: J2.3, J4.13, SW25.2, SW26.2, SW27.2, SW28.2, SW29.2, SW30.2
/Col6: J2.4, J4.14, SW31.2, SW32.2, SW33.2, SW34.2, SW35.2
/MastCaut: D1.2 (A), J2.5, J4.15
/Mode: J3.3, J5.9, J8.1, SW37.2 (B)
/RST: J4.3, J5.3, J6.6, J7.1, SW36.2
/Row1: J3.6, J5.12, SW1.1, SW7.1, SW13.1, SW19.1, SW25.1, SW31.1
/Row2: J3.5, J5.11, SW2.1, SW8.1, SW14.1, SW20.1, SW26.1, SW32.1
/Row3: J1.3, J4.5, SW3.1, SW9.1, SW15.1, SW21.1, SW27.1, SW33.1
/Row4: J1.4, J4.6, SW4.1, SW10.1, SW16.1, SW22.1, SW28.1, SW34.1
/Row5: J1.5, J4.7, SW5.1, SW11.1, SW17.1, SW23.1, SW29.1, SW35.1
/Row6: J1.6, J4.8, SW6.1, SW12.1, SW18.1, SW24.1, SW30.1
GND: J2.7, J4.4, J5.2, J6.2, J6.3, J7.2, J8.2, R1.1, SW36.1, SW37.1 (A)
unnamed: D1.1 (K), R1.2

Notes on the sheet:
NC 0
NC 1
NC 13
GND
NC AREF
NC SDA
NC SCL
NC A5
NC A4
NC A3
NC A2
NC RST
NC RXD
NC TXD
NC A6
NC A7
NC 3.3V
NC 5V
NC VIN
Arduino Nano Sockets
Arduino Uno Pins
Row Digital Pins (A0,A1,2,3,4,5) Col Digital Pins (6,7,8,9,10,11) LED Output for Master Caution, Pin 12 Designed for plug in compatibility with Arduino UNO and Nano
Mode Switch: Open for A-10 Closed for F-18
VIN
3.3V
RST
IOREF

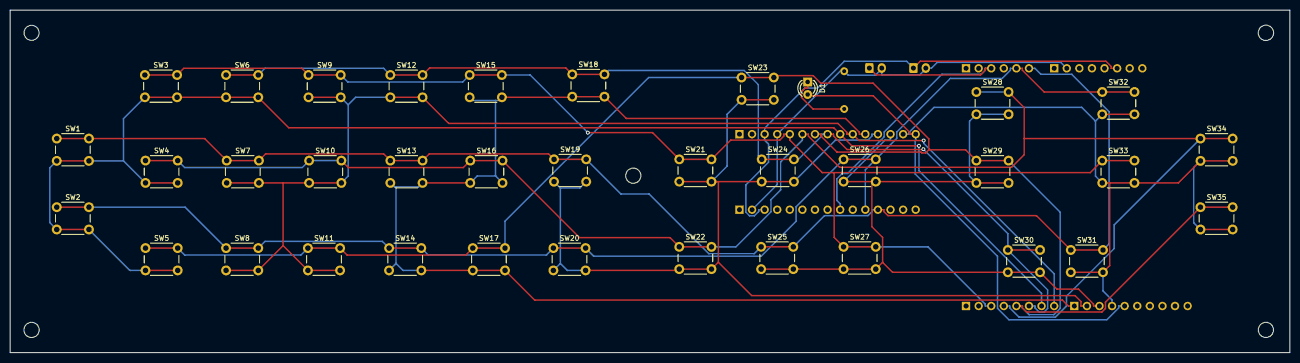
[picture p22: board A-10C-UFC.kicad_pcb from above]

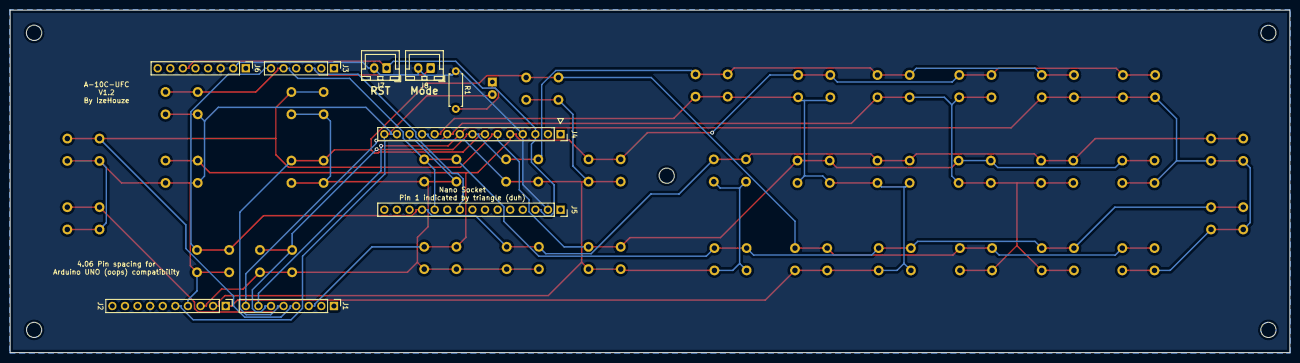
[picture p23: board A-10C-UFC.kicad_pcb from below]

Board: 2 copper layers, 258.2 x 69.1 mm, 45 parts (9 on the bottom side), 17 nets.

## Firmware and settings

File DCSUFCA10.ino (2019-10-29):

/*  A-10C
  This code is written for the custom PCB V1.1 created by Izehouze for the A-10C
  You may need to adjust the letters/numbers in the Rows Cols list if you have created your own panel
  As shown below this uses the

  Keypad Library for Arduino
  Authors:  Mark Stanley, Alexander Brevig

  and DCS-BIOS from http://dcs-bios.a10c.de/

*/
#define DCSBIOS_DEFAULT_SERIAL
#include "DcsBios.h"
#include <Keypad.h>

const int led = 13;
const byte ROWS = 6; // Six rows
const byte COLS = 6; // Six columns

// Define the Keymap
char keys[ROWS][COLS] = {
  {'S', '5', '0', 'M', '$', 'B'},
  {'s', '8', 'c', 'a', '%', 'R'},
  {'1', '3', 'F', '!', '^', 'r'},
  {'4', '6', 'L', '@', 'P', 'D'},
  {'7', '9', 'C', 'e', 'p', 'd'},
  {'2', 'H', 'E', '#', 'b'}
};

// Connect keypad ROW0, ROW1, ROW2 and ROW3 to these Arduino pins.
byte rowPins[ROWS] = { A0, A1, 2, 3, 4, 5 };
// Connect keypad COL0, COL1 and COL2 to these Arduino pins.
byte colPins[COLS] = { 6, 7, 8, 9, 10, 11 };

// Create the Keypad
Keypad kpd = Keypad( makeKeymap(keys), rowPins, colPins, ROWS, COLS );

bool sState = false;
char AC[] = "A10";
char mastCautReset[] = "MASTER_CAUTION_RESET_SW";
char spcAP[] = "UFC_SPC";
char clrIFF[] = "UFC_CLR";
char strClr[] = "UFC_STEER";
char altTCN[] = "UFC_ALT_ALRT";
char cm2ILS[] = "EPP_BATTERY_PWR";
char eccmDL[] = "EPP_INVERTER";
char idmBCN[] = "EPP_APU_GEN_PWR";
char intenON[] = "UFC_INTEN";
char X0[] = "UFC_10";

void flash(int count)
{
  pinMode(12,OUTPUT);
  for (int i = 0; i < count; i++)
  {
    digitalWrite(12,HIGH);
    delay(500);
    digitalWrite(12,LOW);
    delay(500);
  }
}

void setA10()
{
  //Variables below function as a way to alter button functions based on the AC Mode Selected.
  flash(2);
  strcpy(AC , "A10");
  digitalWrite(led, HIGH);
  strcpy(mastCautReset, "UFC_MASTER_CAUTION");
  strcpy(spcAP, "UFC_SPC");
  strcpy(clrIFF, "UFC_CLR");
  strcpy(strClr, "UFC_STEER");
  strcpy(altTCN, "UFC_ALT_ALRT");
  strcpy(cm2ILS, "EPP_BATTERY_PWR");
  strcpy(eccmDL, "EPP_INVERTER");
  strcpy(idmBCN, "EPP_APU_GEN_PWR");
  strcpy(intenON, "UFC_INTEN");
  strcpy(X0, "UFC_10");
  DcsBios::LED masterCaution(0x1012, 0x0800, 12);
}

void setF18()
{
  flash(4);
  strcpy(AC, "F18");
  digitalWrite(led, LOW);
  strcpy(mastCautReset, "MASTER_CAUTION_RESET_SW");
  strcpy(spcAP, "UFC_AP");
  strcpy(clrIFF, "UFC_IFF");
  strcpy(strClr, "UFC_CLR");
  strcpy(altTCN, "UFC_TCN");
  strcpy(cm2ILS, "UFC_ILS");
  strcpy(eccmDL, "UFC_DL");
  strcpy(idmBCN, "UFC_BCN");
  strcpy(intenON, "UFC_ONOFF");
  strcpy(X0, "UFC_0");
  DcsBios::LED masterCaution(0x7408, 0x0200, 12);
}

void setup()
{
  pinMode(led, OUTPUT);
  pinMode(A3, INPUT_PULLUP);
  sState = digitalRead(A3);
  if (sState) {
    setA10();
  }
  else {
    setF18();
  }

  DcsBios::setup();
  kpd.addEventListener(keypadEvent);  // Add an event listener.
  kpd.setHoldTime(100);               // Default is 1000mS
  kpd.setDebounceTime(50);           // Default is 50mS
}

void loop()
{
  DcsBios::loop();
  char key = kpd.getKey();
}

void keypadEvent(KeypadEvent KEY) {
  switch (kpd.getState()) { // gives PRESSED, HOLD or RELEASED
    case PRESSED:
      switch (KEY) {
        //UFC
        case 'S': sendDcsBiosMessage("UFC_STEER", "2"); break;
        case 's': {
            if (strcmp(AC, "A10") == 0) {
              sendDcsBiosMessage(strClr, "0");
              break;
            }
            else {
              sendDcsBiosMessage(strClr, "1");
              break;
            }
          }        
        case '1': sendDcsBiosMessage("UFC_1", "1"); break;
        case '4': sendDcsBiosMessage("UFC_4", "1"); break;
        case '7': sendDcsBiosMessage("UFC_7", "1"); break;
        case '2': sendDcsBiosMessage("UFC_2", "1"); break;
        case '5': sendDcsBiosMessage("UFC_5", "1"); break;
        case '8': sendDcsBiosMessage("UFC_8", "1"); break;
        case '3': sendDcsBiosMessage("UFC_3", "1"); break;
        case '6': sendDcsBiosMessage("UFC_6", "1"); break;
        case '9': sendDcsBiosMessage("UFC_9", "1"); break;
        case 'H': sendDcsBiosMessage("UFC_HACK", "1"); break;
        case '0': sendDcsBiosMessage(X0, "1"); break;
        case 'c': sendDcsBiosMessage(spcAP, "1"); break;
        case 'F': sendDcsBiosMessage("UFC_FUNC", "1"); break;
        case 'L': sendDcsBiosMessage("UFC_LTR", "1"); break;
        case 'C': sendDcsBiosMessage(clrIFF, "1"); break;
        case 'E': sendDcsBiosMessage("UFC_ENT", "1"); break;
        case 'M': sendDcsBiosMessage("UFC_MK", "1"); break;
        case 'a': sendDcsBiosMessage(altTCN, "1"); break;
        case 'e': sendDcsBiosMessage(mastCautReset, "1"); break;
        /* Original code for the unused 6 buttons on the UFC.
            Items re-assigned to be something useful below.
           case '!': sendDcsBiosMessage("UFC_NA1", "1"); break;
           case '@': sendDcsBiosMessage("UFC_NA4", "1"); break;
           case '#': sendDcsBiosMessage("UFC_NA2", "1"); break;
           case '$': sendDcsBiosMessage("UFC_NA5", "1"); break;
           case '%': sendDcsBiosMessage("UFC_NA3", "1"); break;
           case '^': sendDcsBiosMessage("UFC_NA6", "1"); break;
        */
        case '!': sendDcsBiosMessage("EPP_BATTERY_PWR", "1"); break;
        case '@': {
            if (strcmp(AC, "A10") == 0) {
              sendDcsBiosMessage(cm2ILS, "0");
              break;
            }
            else {
              sendDcsBiosMessage(cm2ILS, "1");
              break;
            }
          }

        case '#': sendDcsBiosMessage("EPP_INVERTER", "2"); break;
        case '$': sendDcsBiosMessage(eccmDL, "1"); break;
        case '%': sendDcsBiosMessage("EPP_APU_GEN_PWR", "1"); break;
        case '^': {
            if (strcmp(AC, "A10") == 0) {
              sendDcsBiosMessage(idmBCN, "0");
              break;
            }
            else {
              sendDcsBiosMessage(idmBCN, "1");
              break;
            }
          }
        case 'P': sendDcsBiosMessage("UFC_DATA", "2"); break;
        case 'p': sendDcsBiosMessage("UFC_DATA", "0"); break;
        case 'b': {
            if (strcmp(AC, "A10") == 0) {
              sendDcsBiosMessage(intenON, "0");
              break;
            }
            else {
              sendDcsBiosMessage(intenON, "1");
              break;
            }
          }
        case 'B': sendDcsBiosMessage("UFC_INTEN", "2"); break;
        case 'R': sendDcsBiosMessage("UFC_SEL", "2"); break;
        case 'r': sendDcsBiosMessage("UFC_SEL", "0"); break;
        case 'D': sendDcsBiosMessage("UFC_DEPR", "2"); break;
        case 'd': sendDcsBiosMessage("UFC_DEPR", "0"); break;
      }
  }

  switch (kpd.getState()) { // gives PRESSED, HOLD or RELEASED
    case RELEASED: // LMFD
      switch (KEY) { // Released KEYs or Neutral Rockers signal is sent
        //UFC
        case 'S': sendDcsBiosMessage("UFC_STEER", "1"); break;
        case 's': {
            if (strcmp(AC, "A10") == 0) {
              sendDcsBiosMessage(strClr, "1");
              break;
            }
            else {
              sendDcsBiosMessage(strClr, "0");
              break;
            }
          }        
        case '1': sendDcsBiosMessage("UFC_1", "0"); break;
        case '4': sendDcsBiosMessage("UFC_4", "0"); break;
        case '7': sendDcsBiosMessage("UFC_7", "0"); break;
        case '2': sendDcsBiosMessage("UFC_2", "0"); break;
        case '5': sendDcsBiosMessage("UFC_5", "0"); break;
        case '8': sendDcsBiosMessage("UFC_8", "0"); break;
        case '3': sendDcsBiosMessage("UFC_3", "0"); break;
        case '6': sendDcsBiosMessage("UFC_6", "0"); break;
        case '9': sendDcsBiosMessage("UFC_9", "0"); break;
        case 'H': sendDcsBiosMessage("UFC_HACK", "0"); break;
        case '0': sendDcsBiosMessage(X0, "0"); break;
        case 'c': sendDcsBiosMessage(spcAP, "0"); break;
        case 'F': sendDcsBiosMessage("UFC_FUNC", "0"); break;
        case 'L': sendDcsBiosMessage("UFC_LTR", "0"); break;
        case 'C': sendDcsBiosMessage(clrIFF, "0"); break;
        case 'E': sendDcsBiosMessage("UFC_ENT", "0"); break;
        case 'M': sendDcsBiosMessage("UFC_MK", "0"); break;
        case 'a': sendDcsBiosMessage(altTCN, "0"); break;
        case 'e': sendDcsBiosMessage(mastCautReset, "0"); break;
        case '!': sendDcsBiosMessage("UFC_NA1", "0"); break;
        case '@': sendDcsBiosMessage(cm2ILS, "0"); break;
        case '#': sendDcsBiosMessage("UFC_NA2", "0"); break;
        case '$': {
            if (strcmp(AC, "A10") == 0) {
              sendDcsBiosMessage(eccmDL, "1");
              break;
            }
            else {
              sendDcsBiosMessage(eccmDL, "0");
              break;
            }
          }
        case '%': sendDcsBiosMessage("UFC_NA3", "0"); break;
        case '^': sendDcsBiosMessage(idmBCN, "0"); break;
        case 'P': sendDcsBiosMessage("UFC_DATA", "1"); break;
        case 'p': sendDcsBiosMessage("UFC_DATA", "1"); break;
        case 'b': {
            if (strcmp(AC, "A10") == 0) {
              sendDcsBiosMessage(intenON, "1");
              break;
            }
            else {
              sendDcsBiosMessage(intenON, "0");
              break;
            }
          }
        case 'B': sendDcsBiosMessage("UFC_INTEN", "1"); break;
        case 'R': sendDcsBiosMessage("UFC_SEL", "1"); break;
        case 'r': sendDcsBiosMessage("UFC_SEL", "1"); break;
        case 'D': sendDcsBiosMessage("UFC_DEPR", "1"); break;
        case 'd': sendDcsBiosMessage("UFC_DEPR", "1"); break;
      }
  }
}

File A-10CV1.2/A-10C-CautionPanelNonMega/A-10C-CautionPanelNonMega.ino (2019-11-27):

/*  A-10C
  This code is written for the custom PCB V1.0 of the Cuation Lights Panel created by Izehouze for the A-10C.
  It depends on the following library.

  DCS-BIOS from http://dcs-bios.a10c.de/

*/
#define DCSBIOS_DEFAULT_SERIAL
#include "DcsBios.h"

byte dataPin[8] = {10, 9, 8, 7, 6, 5, 4, 2};
byte pwmPin = 3;
byte clockBit = 11;
byte clockPulse = 12;
byte sensorPin = A0;
byte oePin = A1;

void setup() {
  pinMode(clockBit, OUTPUT);
  pinMode(clockPulse, OUTPUT);
  pinMode(oePin, OUTPUT);
  for (int i = 0; i < 8; i++) {
    pinMode(dataPin[i], OUTPUT);
  }
  DcsBios::setup();
}

void updateCautionLights(unsigned int address, unsigned int data) {
  unsigned char row = (address - 0x10d4) * 2;
  unsigned char column = 0;
  unsigned char i;
  bool is_on;
  int bitID = 7;
  for (i = 0; i < 16; i++) {
    is_on = data & 0x01;
    // set caution light state (row, column, is_on)
    digitalWrite(dataPin[bitID], is_on);
    data >>= 1;
    column++;
    if (column == 4) {
      row++;
      column = 0;
    }
    bitID--;
    if (bitID == -1) {    //Register full, set pulse for shift register.  Will be ready for output latch 0 (of 6) if no other actions taken.
      digitalWrite(clockBit, HIGH);
      digitalWrite(clockPulse, HIGH);
      digitalWrite(clockPulse, LOW);
      digitalWrite(clockBit, LOW);
      int s = (row - 2) / 2;
      int c = 0;
      while (s > c) { //Step to correct output latch
        digitalWrite(clockPulse, HIGH);
        digitalWrite(clockPulse, LOW);
        c++;
      }
      digitalWrite(oePin, HIGH); //Enable output latch to accept values.
      digitalWrite(oePin, LOW);
      for (c = 0; c <= 8; c++) { //Step shift register to a safe position for next run.
        digitalWrite(clockPulse, HIGH);
        digitalWrite(clockPulse, LOW);
      }
      bitID = 7;
      for (c = 7; c >= 0; c--) { //Reset bits on bus before next itteration.
        digitalWrite(dataPin[c], LOW);
      }
    }
  }
}

void onClAUpdate(unsigned int updatedValues) {
  updateCautionLights(0x10d4, updatedValues);
}

void onClBUpdate(unsigned int updatedValues) {
  updateCautionLights(0x10d6, updatedValues);
}

void onClCUpdate(unsigned int updatedValues) {
  updateCautionLights(0x10d8, updatedValues);
}

DcsBios::IntegerBuffer cautionLightsA( 0x10d4, 0xffff, 0, onClAUpdate );
DcsBios::IntegerBuffer cautionLightsB( 0x10d6, 0xffff, 0, onClBUpdate );
DcsBios::IntegerBuffer cautionLightsC( 0x10d8, 0xffff, 0, onClCUpdate );

void loop() {
  analogWrite(pwmPin, map(analogRead(sensorPin), 0, 1023, 0, 255));
  DcsBios::loop();
}

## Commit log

2019-08-03 Added KiCAD files and FPD file
    [A-10C-UFC-B.CrtYd.gbr, A-10C-UFC-B.Cu.gbr, A-10C-UFC-B.Mask.gbr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]
2019-08-04 Updated for multi aircraft capability. Added wiring and code.
    [A-10C-UFC.dsn, A-10C-UFC.kicad_pcb, A-10C-UFC.sch]
2019-08-05 Added multi aircraft support code into Arduino
2019-08-05 Corrected some code warnings
    [DCSUFCA10.ino]
2019-08-08 Updated front panel drills points
2019-08-08 Building blender model of case and buttons started.
2019-08-09 More blending
    [A10UFC-Tinker.blend]
2019-08-09 Updating Models
    [A10UFC.blend]
2019-08-10 Updating everything
    [A-10C-UFC.kicad_pcb, A10UFC-Tinker.blend, UFC.dxf]
2019-08-10 More updates
    [A10UFC.blend]
2019-08-11 just refining the mode for symetry
    [A10UFC.blend]
2019-08-12 Corrected version number to 1.2
    [A-10C-UFC-B.CrtYd.gbr, A-10C-UFC-B.Cu.gbr, A-10C-UFC-B.Mask.gbr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]
2019-08-12 more revisions
    [A-10C-UFC.kicad_pcb, A10UFC.blend]
2019-08-13 Fixing holes in model?
    [A10UFC.blend, A10UFC.stl]
2019-08-13 Always tweaking board shapes.
    [A-10C-UFC.dsn, A-10C-UFC.kicad_pcb]
2019-08-16 Updated PCB to move headers further inboard from edge
    [A-10C-UFC.dsn, A-10C-UFC.kicad_pcb, A10UFC.blend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]
2019-08-16 Forgot some
    [A-10C-UFC.sch]
2019-08-18 Always finding little imperfections.
    [A-10C-UFC-B.CrtYd.gbr, A-10C-UFC-B.Cu.gbr, A-10C-UFC-B.Mask.gbr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]
2019-09-11 Fixed Pins for final version with live board.
    [DCSUFCA10.ino]
2019-09-12 Found a weird bug that strcpy on the Master Caution causes certain keys to stop reading in F-18 mode. Switched it to an improper pointer/variable, and it works fine.
    [DCSUFCA10.ino]
2019-09-14 Cleaning up un-needed files.
    [A10UFC-Tinker.blend, A10UFC.stl, test.stl]
2019-09-14 Created a new Case that is considered "Manifold" for printing purposes.
    [A10UFCRev.blend]
2019-09-15 Adjusted blender mode stud length to match more closely to real world board dimentions.
    [A10UFCRev.blend]
2019-09-18 Created quick button LED test sketch.
2019-09-18 Fixed copi pasta issues.
    [UFCButtonTest.ino]
2019-10-26 Added new designs for a Caution Lights Panel.
    [A-10C-CautionLED-Edge_Cuts.dxf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]
2019-10-28 First bits of working code completed. May be changed in favor of single event vs 48 events.
    [A-10C-CautionPanelNonMega.dsn, A-10C-CautionPanelNonMega.kicad_pcb, A-10C-CautionPanelNonMega.sch]
2019-10-28 Switched to using the IntegerBuffer to get all of the Caution Light values instead of individual calls.
2019-10-28 Correct regulator model
    [A-10C-CautionPanelNonMega.sch]
2019-10-29 Updated code for DCS Panels branch of code to match new DCS-BIOS Branch. Updated the FA-18 Master Caution light address. Updated the UFC 0 key to UFC_0 for the FA-18. Added switch mode code for the d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
2019-11-05 Tweaking timing for Nano to 8 bit interface.
    [A-10C-CautionPanelNonMega.kicad_pcb, A-10C-CautionPanelNonMega.sch]
2019-11-06 Updated Anano Pin Labels
    [A-10C-CautionPanelNonMega.sch]
2019-11-06 Updating RS port to three pin
    [A-10C-CautionPanelNonMega.dsn, A-10C-CautionPanelNonMega.kicad_pcb, A-10C-CautionPanelNonMega.sch]
2019-11-27 Saving before PC reset
    [A-10C-CautionPanelNonMega.dsn, A-10C-CautionPanelNonMega.kicad_pcb]
2020-08-03 Added a sample export STL of the UFC Case
    [UFCCase.stl]
